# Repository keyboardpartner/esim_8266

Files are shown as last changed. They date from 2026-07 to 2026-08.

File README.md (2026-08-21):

# EPROM Simulator Uploader

### ESP8266 Project for PlatformIO with Arduino Framework

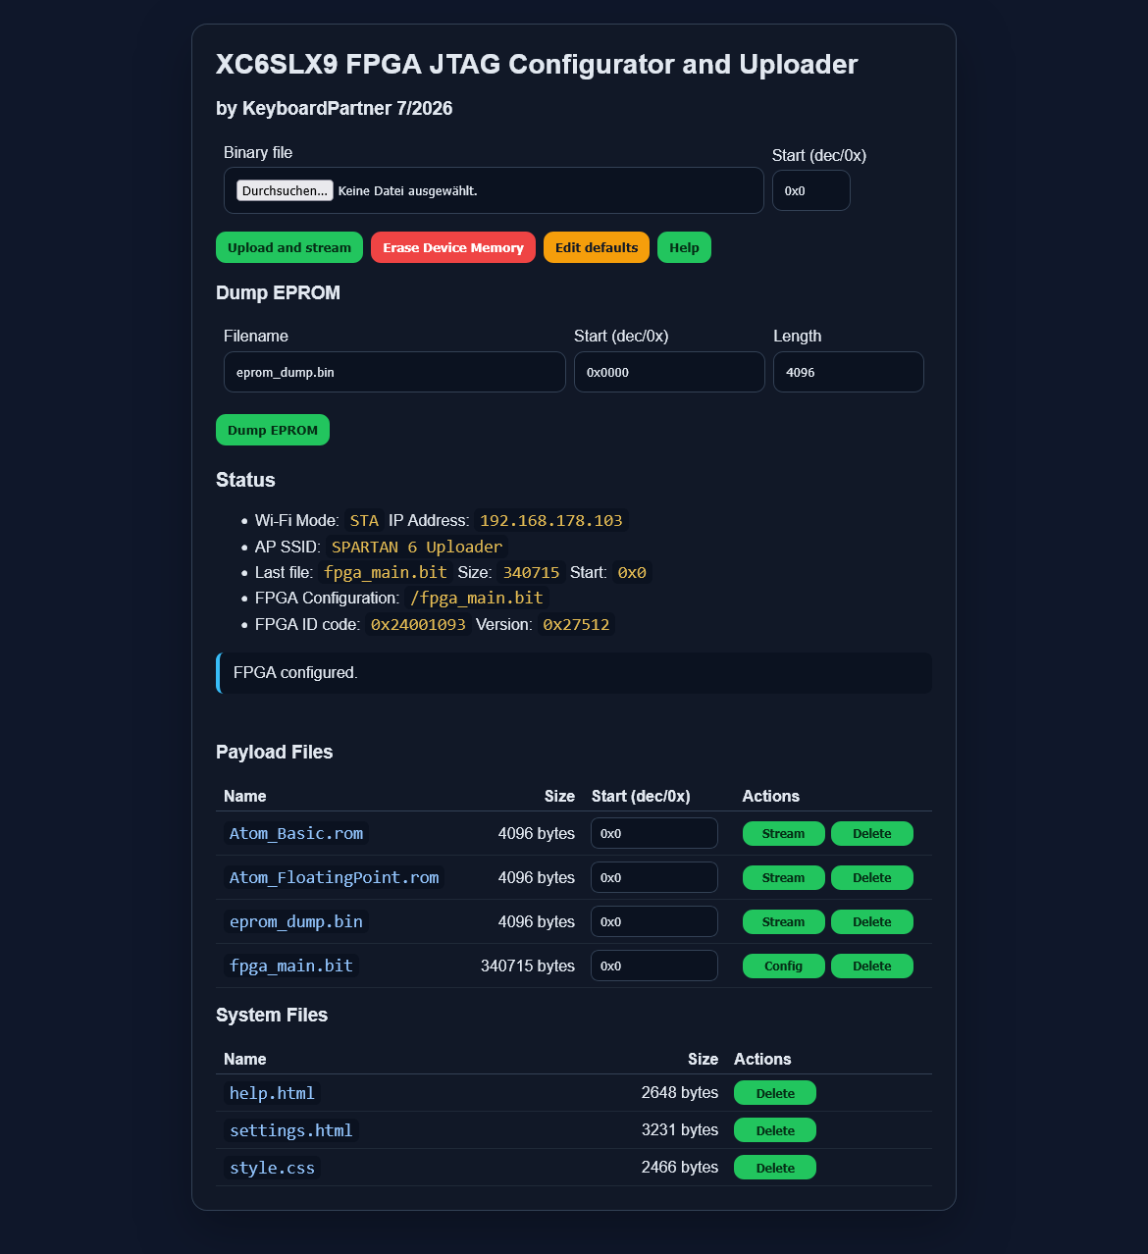
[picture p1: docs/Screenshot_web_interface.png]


For development of legacy computer systems and embedded controllers, an EPROM simulator is mandatory. Unfortunately, they are no longer popular and availability is sparse, while older models lack an appropriate interface. I made a few versions shown here. Set *#defines* in *main.cpp* accordingly.

The ESP8266 provides a nice web interface along with help page. For use without web interface, my [ESP8266 EPROM/SRAM Simulator Uploader](https://github.com/keyboardpartner/ESIM_Uploader) may be used to transfer files to the device.

### MOJO V3 FPGA Support

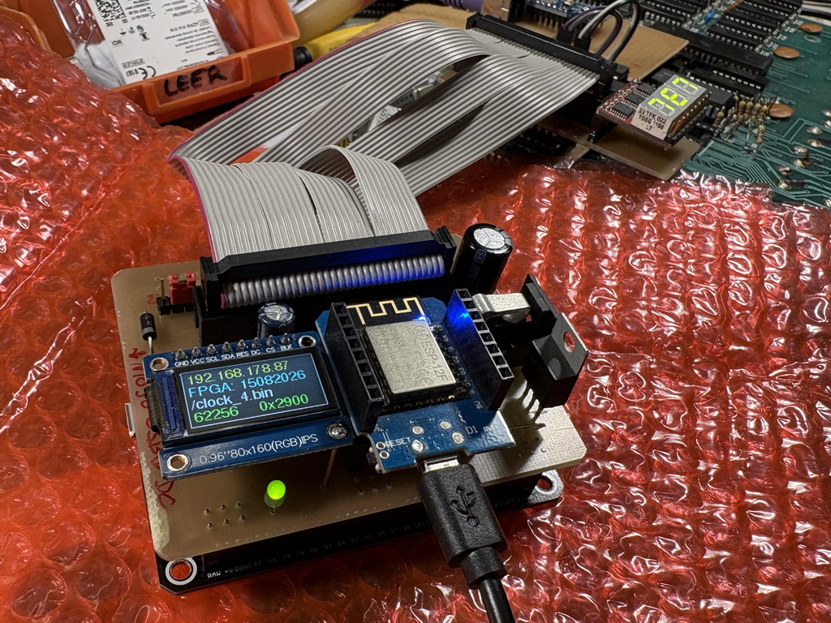
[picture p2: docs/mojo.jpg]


Using a MOJO V3 FPGA board as EPROM simulator allows for 64 KByte EPROMs and SRAMs, merely by using internal FPGA BRAMs. MOJO is a FPGA board from *embeddedmicro.com*, formerly advertized as "open source". Unfortunately, the manufacturer ceased operation, and documentation is sparse now. This is how not to do "open source"!

However, some cheap rip-offs are still available through Aliexpress. The original MOJO design is rather bad, using an AVR for (slowly!) uploading the configuration bitstream from an SPI flash via *Master SelectMAP* mode (instead of attaching the SPI flash direcly to FPGA; by blocking the FPGA, flashing would have been possible as well).

I once made a [MOJO BIT file Uploader for Windows](https://github.com/keyboardpartner/MOJO_uploader) that flashes the SPI memory, but here a different approach is used: I send the FPGA configuration through JTAG (pins available on MOJO SV1). So the FPGA configuration may be uploaded and selected by web interface on-the-fly. The AVR on MOJO board is blocked by permanent reset. My fast JTAG loader sends the 334 KByte bitstream file for FPGA XILINX XC6SLX9 from LittleFS in about 920 ms (instead of 3.4 seconds of known version from RSP, see below), which is even faster than the ill-fated MOJO approach.

For MOJO-like boards with Xilinx XC9SLX9 FPGA, ensure the correct bitstream (default "fpga_main.bit") is uploaded to file system. The bitstream is loaded into the FPGA during startup configuration via JTAG.

This version can be used as RAM emulator for 6264 or 62256 SRAMs, like the GODIL version. Note that MOJO **does not provide logic level translators**. I think a 220R resistor in series to each logic line will do, protecting inputs from host circuit's 5V levels. Tested with several old home computers; seems they all work with 3.3V logic levels.

The MOJO version supports the following devices: 2716, 2732, 2764, 27128, 27256 and 27512 EPROMs, 2532 EPROMs, 2332 and 2364 PROMs, 6116, 6264 and 62256 SRAMs, PicoBlaze 3 and 6 core ROMs. I also plan for a MOS 6502 emulation with monitor functions.

### 0.96" TFT Support

A 0.96" TFT (optional) displays status messages, IP number, FPGA image version, file used, device emulated and start address info for the MOJO version. The TFT will work on other versions (instead of DY1 display) too, but only the MOJO PCB provides installation.

### ESIM Support

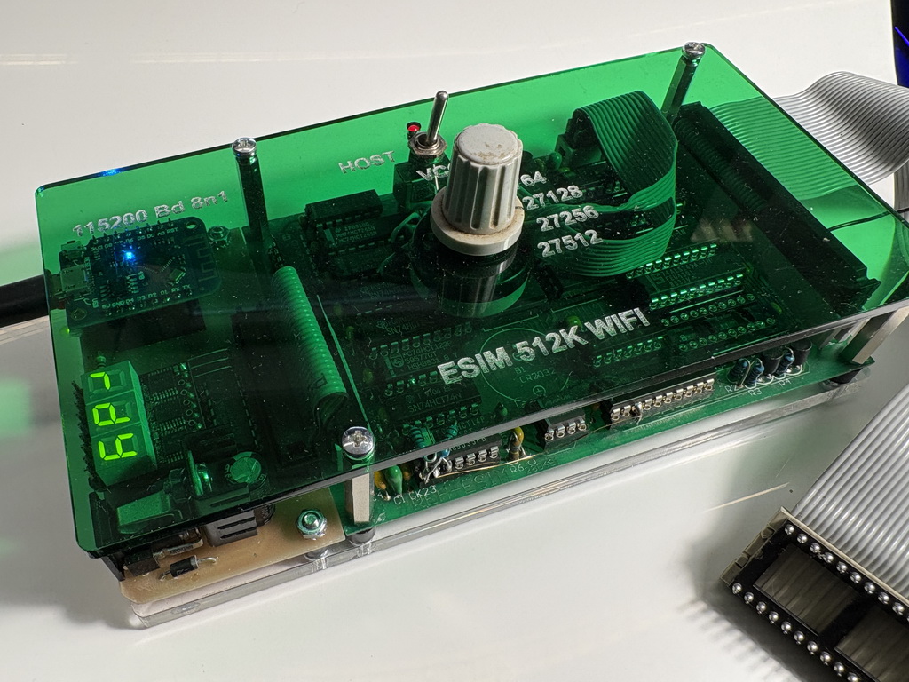
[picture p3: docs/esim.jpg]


ESP8266 used as an upload tool for old ESIM EPROM Simulator from c't magazine, issue 9/1991. Instead of obsolete Centronix port, outputs stream of data to 74HC595 shift register. Pulls /STROBE low on each byte sent. Supports 2764 up tp 27512 EPROMs. Unfortunately, ESIM does not support readback or setting a start address; uploads will always start at EPROM address 0x0000.

#### Pinout ESIM

Centronix Sub-D-25 for IBM PC, box pin header, 26 pins. Sub-D-25 pins in brackets

| PFS-26 Pin | Sub-D-25 Pin | Signal | PFS-26 Pin | Sub-D-25 Pin | Signal |
| --- | --- | --- | --- | --- | --- |
| 1  | (1)  | /STB | 2  | (14) | nc |
| 3  | (2)  | D0 | 4  | (15) | nc |
| 5  | (3)  | D1 | 6  | (16) | nc |
| 7  | (4)  | D2 | 8  | (17) | nc |
| 9  | (5)  | D3 | 10 | (18) | GND |
| 11 | (6)  | D4 | 12 | (19) | GND |
| 13 | (7)  | D5 | 14 | (20) | GND |
| 15 | (8)  | D6 | 16 | (21) | GND |
| 17 | (9)  | D7 | 18 | (22) | GND |
| 19 | (10) | nc (ACK) | 20 | (23) | GND |
| 21 | (11) | GND (BUSY) | 22 | (24) | GND |
| 23 | (12) | nc | 24 | (25) | GND |
| 25 | (13) | VCC-Host | 26 | (-)  | VCC-Host |

### CONITEC PEPS Support

New: now supports even older PEPS EPROM Simulator from c't 5/1985, page 85. This design uses a special serial transmission; due to the protocol's nature, the byte output routine uses slower bit-banging instead of SPI. EPROM size is limited to 27128 (16 KBytes). Find the old article in /docs folder.

### GODIL FPGA Support

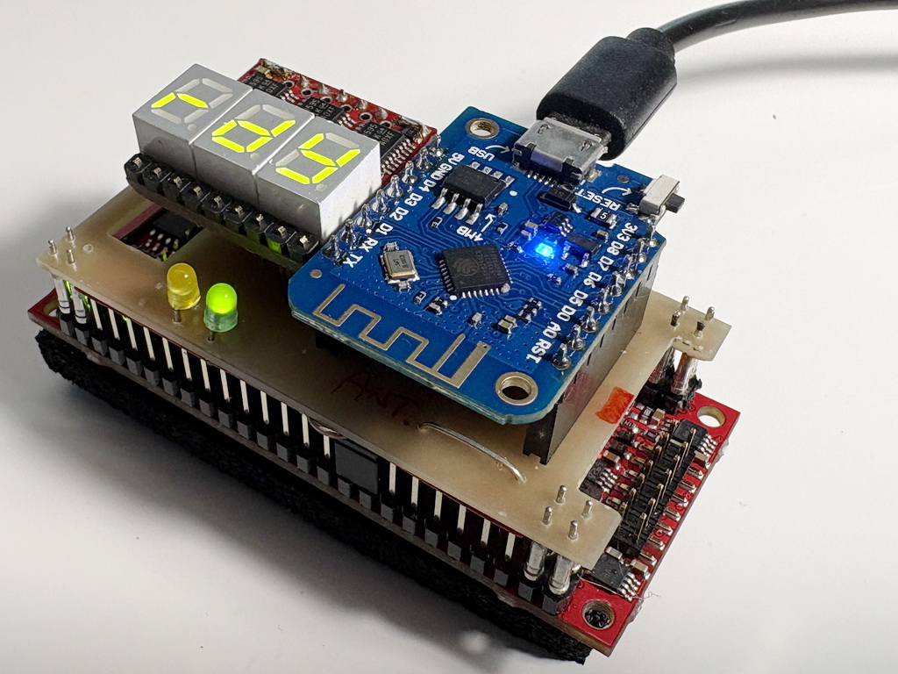
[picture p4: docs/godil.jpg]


Uses the now legendary GODIL 40 from [OHO electronic](https://www.oho-elektronik.de/). These are FPGA modules sold by [Trenz electronic](https://www.trenz-electronic.de/de) some time ago, but you may still find them on the web. Supports EPROMs up to 27256 (32 KByte) due to limitations of internal FPGA BRAMs. Needs some jumpers for Vcc on GODIL, as to switch between 24-pin and 28-pin EPROMs. GODIL has internal logic level translators, so it is compatible with 5V systems.

As well as the MOJO version, it can be used as RAM emulator for 6264 or 62256 SRAMs; in this case, you may read back the RAM contents from host system. Used it to recover old programs from my very first computer, an Acorn ATOM from 1981, using the rom_adapter_2 circuit. See /pcb folder. 

You need a JTAG adaptor to program GODIL's internal SPI flash. Prepare to do some VHDL coding, as this version does not provide features seen on the MOJO version.

### OHO DY1 Support

All modules support the OHO DY1 display, a 3-digit 7-segment LED module with SPI connection, handy for displaying short messages, IP numbers etc. You may omit the DY1 display and use serial monitoring instead (to get your IP number and to set password/SSID).

### PCBs

For each version, I designed a one-layer PCB optimized for milling. Can be handled by JCLPCB, though. There are also designs for ROM/RAM adaptors. See /pcb folder. 

PCB design done with EasyPC from NumberOne Systems.

Useful links:

[ESP8266 EPROM/SRAM Simulator Uploader](https://github.com/keyboardpartner/ESIM_Uploader) Windows CLI Upload tool, sends files to EPROM Simulator Uploader via COM port instead of web interface

[MOJO BIT file Uploader for Windows](https://github.com/keyboardpartner/MOJO_uploader) (not needed here, but anyway)

[MOJO v3 Bootloader and firmware](https://github.com/embmicro/mojo-bootloader/blob/master/Caterina.c)

[JTAG Player for ESP8266](https://github.com/rsp-esl/esp8266_jtag_fpga) (slow, as mentioned above)

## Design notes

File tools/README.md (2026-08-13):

# Tools for EPROM Simulator Uploader

### GODIL Tools



For programming the GODIL's internal SPI flash, you need a JTAG adaptor from Digilent like JTAG-SPI USB Full-Speed RevC or never. While the FPGA can be loaded with *Digilent Adept* app (volatile, good for development), you need the CLI-based Digilent *sfutil.exe* to permanently store the FPGA configuration in it's SPI flash. Provided here are two drag & drop capable batch files to read the flash mem's ID code and to program it via *sfutil.exe*.

Useful links:

[Digilent Adept Overview](https://digilent.com/shop/software/digilent-adept/)

[Digilent Adept Download](https://lp.digilent.com/complete-adept-utilities-download)

[Digilent SFUTIL SPI flash utility (Windows)](https://digilent.com/reference/software/serial-flash-utility/start)

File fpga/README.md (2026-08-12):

# EPROM Simulator Uploader - FPGA Sources

Copy contents to own Xilinx ISE FPGA project folder and open fpga_main.xise there. Add **one** UCF file (pin assignment) to your project (either GODIL or MOJO, not both). Also add memory IP core (*sram_32k.xco* for GODIL and *sram64k.xco* for MOJO) from *ipcore_dir* directory.

Data exchange happens through a 32-bit SPI register in FPGA. See *bram_wrapper.vhd* for SPI command set.

### Note to myself: Sources must be copied to this folder manually due to complexity of Xilinx ISE projects. Do not run ISE in this folder as it creates a mess.

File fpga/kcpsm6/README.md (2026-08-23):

# MOJO Picoblaze Demo

The XILINX Webpack ISE project *MojoFPGA_Picoblaze.xise* contains a Picoblaze CPU core which lets the onboard-LEDs blink, demonstrating the upload of Picoblaze Instruction ROM instead of using "hard-wired" BRAM contents defined in VHDL synthesis. 

After uploading the *mojo_pb_test.bit* configuration, stream the *picoblaze_test.dat* file to the Mojo FPGA using the Upload web page provided by the ESP8266.

For convenience, we provide a Drag&Drop batch file for [Ken Chapmman's 6-series picoblaze assembler](https://www.amd.com/en/products/adaptive-socs-and-fpgas/intellectual-property/picoblaze.html) for Windows PCs.

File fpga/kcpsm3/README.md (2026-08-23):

# MOJO Picoblaze Demo

The XILINX Webpack ISE project *MojoFPGA_Picoblaze.xise* contains a Picoblaze CPU core which lets the onboard-LEDs blink, demonstrating the upload of Picoblaze Instruction ROM instead of using a "hard-wired" BRAM contents defined in VHDL synthesis. This might be used for the GODIL as well (needs some project changes).

For convenience, we provide a compiled version of [Jan Viktorin's picoblaze assembler](https://github.com/jviki/kcpsm3) for Windows PCs and a Drag&Drop batch file. Note that Ken Chapman's original KCPSM3 no longer works on 64-Bit Windows.

After uploading the *mojo_pb_test.bit* configuration, stream the *picoblaze_test.dat* file to the Mojo FPGA using the Upload web page provided by the ESP8266.

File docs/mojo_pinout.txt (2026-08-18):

SV	SV Pin	FPGA UCF Pin	Function	ESP Pin
SV1	1		GND	
SV1	2		VCC 5V	
SV1	3		GND	
SV1	4		VCC 3V3	
SV1	5	P73	SUSPEND	
SV1	6	P71	DONE_2	
SV1	7	P58	IO_L14P_D11_2	
SV1	8	P57	IO_L14N_D12_2	
SV1	9	P67	IO_L2P_CMPCLK_2 	
SV1	10	P66	IO_L2N_CMPMOSI_2 	
SV1	11	P75	IO_L74P_AWAKE_1 	
SV1	12	P74	IO_L74N_DOUT_BUSY_1	
SV1	13	P79	IO_L47P_1 	
SV1	14	P78	IO_L47N_1 	
SV1	15	P81	IO_L46P_1 	
SV1	16	P80	IO_L46N_1 	
SV1	17	P83	IO_L45P_1 	
SV1	19	P85	IO_L43P_GCLK5_1 	
SV1	19	P82	IO_L45N_1 	
SV1	20	P84	IO_L43N_GCLK4_1 	
SV1	21	P88	IO_L42P_GCLK7_1 	
SV1	22	P87	IO_L42N_GCLK6_TRDY1_1 	GPIO 15 /SS
SV1	23	P93	IO_L41P_GCLK9_IRDY1_1 	GPIO 13 MOSI
SV1	24	P92	IO_L41N_GCLK8_1 	GPIO 12 MISO
SV1	25	P95	IO_L40P_GCLK11_1 	GPIO 14 SCLK
SV1	26	P94	IO_L40N_GCLK10_1 	GPIO 16 STRB
SV1	27	P98	IO_L34P_1 	
SV1	28	P97	IO_L34N_1 	
SV1	29	P100	IO_L33P_1 	
SV1	30	P99	IO_L33N_1 	
SV1	31	P102	IO_L32P_1 	
SV1	32	P101	IO_L32N_1 	
SV1	33	P105	IO_L1P_1 	
SV1	34	P104	IO_L1N_VREF_1 	
SV1	35	P112	IO_L66P_SCP1_0 	
SV1	36	P111	IO_L66N_SCP0_0 	
SV1	37	P115	IO_L65P_SCP3_0 	
SV1	38	P114	IO_L65N_SCP2_0 	
SV1	39	P117	IO_L64P_SCP5_0 	
SV1	40	P116	IO_L64N_SCP4_0 	
SV1	41	P119	IO_L63P_SCP7_0 	
SV1	42	P118	IO_L63N_SCP6_0 	
SV1	43	P121	IO_L62P_0 	
SV1	44	P120	IO_L62N_VREF_0 	
SV1	45	P107	TMS 	GPIO 2
SV1	46	P106	TDO 	GPIO 4
SV1	47	P110	TDI 	GPIO 0
SV1	48	P109	TCK 	GPIO 5
SV1	49	P38	IO_L65N_CSO_B_2	
SV1	50		GND	
SV	SV Pin	FPGA UCF Pin	Function	
SV2	1		GND	
SV2	2		VCC 5V	
SV2	3		GND	
SV2	4		VCC 3V3	
SV2	5	P31	IO_L31P_GCLK31_D14_2	
SV2	6	P50	IO_L31N_GCLK30_D15_2	
SV2	7	P41	IO_L64P_2	
SV2	8	P40	IO_L64N_2	
SV2	9	P35	IO_L1P_3 	
SV2	10	P34	IO_L1N_VREF_3 	
SV2	11	P33	IO_L2P_3 	
SV2	12	P32	IO_L2N_3 	
SV2	13	P30	IO_L36P_3 	
SV2	14	P29	IO_L36N_3 	
SV2	15	P27	IO_L37P_3 	
SV2	16	P26	IO_L37N_3 	
SV2	17	P24	IO_L41P_GCLK27_3 	
SV2	18	P23	IO_L41N_GCLK26_3 	
SV2	19	P22	IO_L42P_GCLK25_TRDY2_3 	
SV2	20	P21	IO_L42N_GCLK24_3 	
SV2	21	P17	IO_L43P_GCLK23_3 	
SV2	22	P16	IO_L43N_GCLK22_IRDY2_3 	
SV2	23	P15	IO_L44P_GCLK21_3 	
SV2	24	P14	IO_L44N_GCLK20_3 	
SV2	25	P12	IO_L49P_3 	
SV2	26	P11	IO_L49N_3 	
SV2	27	P10	IO_L50P_3 	
SV2	28	P9	IO_L50N_3 	
SV2	29	P8	IO_L51P_3 	
SV2	30	P7	IO_L51N_3 	
SV2	31	P6	IO_L52P_3 	
SV2	32	P5	IO_L52N_3 	
SV2	33	P2	IO_L83P_3 	
SV2	34	P1	IO_L83N_VREF_3 	
SV2	35	P144	IO_L1P_HSWAPEN_0 	
SV2	36	P143	IO_L1N_VREF_0 	
SV2	37	P142	IO_L2P_0 	
SV2	38	P141	IO_L2N_0 	
SV2	39	P140	IO_L3P_0 	
SV2	40	P139	IO_L3N_0 	
SV2	41	P138	IO_L4P_0 	
SV2	42	P137	IO_L4N_0 	
SV2	43	P134	IO_L34P_GCLK19_0 	
SV2	44	P133	IO_L34N_GCLK18_0 	
SV2	45	P132	IO_L35P_GCLK17_0 	
SV2	46	P131	IO_L35N_GCLK16_0 	
SV2	47	P127	IO_L36P_GCLK15_0 	
SV2	48	P126	IO_L36N_GCLK14_0 	
SV2	49	P124	IO_L37P_GCLK13_0 	
SV2	50	P123	IO_L37N_GCLK12_0

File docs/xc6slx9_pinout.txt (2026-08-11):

Device/Package 6slx9tqg144 Wed Mar 31 17:26:10 2010 

Pin	Bank	BUFIO2	Pin Description 

P144	0	TL	IO_L1P_HSWAPEN_0 
P143	0	TL	IO_L1N_VREF_0 
P142	0	TL	IO_L2P_0 
P141	0	TL	IO_L2N_0 
P140	0	TL	IO_L3P_0 
P139	0	TL	IO_L3N_0 
P138	0	TL	IO_L4P_0 
P137	0	TL	IO_L4N_0 
P134	0	TL	IO_L34P_GCLK19_0 
P133	0	TL	IO_L34N_GCLK18_0 
P132	0	TL	IO_L35P_GCLK17_0 
P131	0	TL	IO_L35N_GCLK16_0 
P127	0	TR	IO_L36P_GCLK15_0 
P126	0	TR	IO_L36N_GCLK14_0 
P124	0	TR	IO_L37P_GCLK13_0 
P123	0	TR	IO_L37N_GCLK12_0 
P121	0	TR	IO_L62P_0 
P120	0	TR	IO_L62N_VREF_0 
P119	0	TR	IO_L63P_SCP7_0 
P118	0	TR	IO_L63N_SCP6_0 
P117	0	TR	IO_L64P_SCP5_0 
P116	0	TR	IO_L64N_SCP4_0 
P115	0	TR	IO_L65P_SCP3_0 
P114	0	TR	IO_L65N_SCP2_0 
P112	0	TR	IO_L66P_SCP1_0 
P111	0	TR	IO_L66N_SCP0_0 
P109	NA	NA	TCK 
P110	NA	NA	TDI 
P107	NA	NA	TMS 
P106	NA	NA	TDO 
P105	1	RT	IO_L1P_1 
P104	1	RT	IO_L1N_VREF_1 
P102	1	RT	IO_L32P_1 
P101	1	RT	IO_L32N_1 
P100	1	RT	IO_L33P_1 
P99	1	RT	IO_L33N_1 
P98	1	RT	IO_L34P_1 
P97	1	RT	IO_L34N_1 
P95	1	RT	IO_L40P_GCLK11_1 
P94	1	RT	IO_L40N_GCLK10_1 
P93	1	RT	IO_L41P_GCLK9_IRDY1_1 
P92	1	RT	IO_L41N_GCLK8_1 
P88	1	RB	IO_L42P_GCLK7_1 
P87	1	RB	IO_L42N_GCLK6_TRDY1_1 
P85	1	RB	IO_L43P_GCLK5_1 
P84	1	RB	IO_L43N_GCLK4_1 
P83	1	RB	IO_L45P_1 
P82	1	RB	IO_L45N_1 
P81	1	RB	IO_L46P_1 
P80	1	RB	IO_L46N_1 
P79	1	RB	IO_L47P_1 
P78	1	RB	IO_L47N_1 
P75	1	RB	IO_L74P_AWAKE_1 
P74	1	RB	IO_L74N_DOUT_BUSY_1           ############  DOUT This output pin is used during readback. 
P73	NA	NA	SUSPEND  
P72	2	NA	CMPCS_B_2 
P71	2	NA	DONE_2                        ############  DONE1 = FPGA configured,  Mojo: AVR PC6
P70	2	BR	IO_L1P_CCLK_2                 ############  CCLK Configuration clock, Mojo: AVR PD0
P69	2	BR	IO_L1N_M0_CMPMISO_2           #### M0 ####  M0  LOW-Pegel = SelectMAP
P67	2	BR	IO_L2P_CMPCLK_2 
P66	2	BR	IO_L2N_CMPMOSI_2 
P65	2	BR	IO_L3P_D0_DIN_MISO_MISO1_2    ############  DIN + SelectMAP D0, Mojo: AVR PB7 (!)
P64	2	BR	IO_L3N_MOSI_CSI_B_MISO0_2     ############  Active-Low chip select to enable the SelectMAP data bus 
P62	2	BR	IO_L12P_D1_MISO2_2            ############  SelectMAP D1, Mojo: AVR PB6 (!)
P61	2	BR	IO_L12N_D2_MISO3_2            ############  SelectMAP D2, Mojo: AVR PB5 (!)
P60	2	BR	IO_L13P_M1_2                  #### M1 ####  M1  HI-Pegel = SelectMAP
P59	2	BR	IO_L13N_D10_2 
P58	2	BR	IO_L14P_D11_2 
P57	2	BR	IO_L14N_D12_2 
P56	2	BR	IO_L30P_GCLK1_D13_2 
P55	2	BR	IO_L30N_GCLK0_USERCCLK_2 
P51	2	BL	IO_L31P_GCLK31_D14_2 
P50	2	BL	IO_L31N_GCLK30_D15_2 
P48	2	BL	IO_L48P_D7_2                  ############  SelectMAP D7, Mojo: AVR SS   PB0 (!)
P47	2	BL	IO_L48N_RDWR_B_VREF_2         ############  Determines the direction of the D[x:0] data bus, 0 = inputs, 1 = outputs
P46	2	BL	IO_L49P_D3_2                  ############  SelectMAP D3, Mojo: AVR PB4 (!)
P45	2	BL	IO_L49N_D4_2                  ############  SelectMAP D4, Mojo: AVR MISO PB3 (!)
P44	2	BL	IO_L62P_D5_2                  ############  SelectMAP D5, Mojo: AVR MOSI PB2 (!)
P43	2	BL	IO_L62N_D6_2                  ############  SelectMAP D6, Mojo: AVR SCK  PB1 (!)
P41	2	BL	IO_L64P_D8_2 
P40	2	BL	IO_L64N_D9_2 
P39	2	BL	IO_L65P_INIT_B_2              ############  Mojo: AVR PD5
P38	2	BL	IO_L65N_CSO_B_2               ############  Not used in single FPGA applications
P37	2	NA	PROGRAM_B_2                   ############  PROGRAM_B Active-Low asynchronous full-chip reset, Mojo: AVR PC7
P35	3	LB	IO_L1P_3 
P34	3	LB	IO_L1N_VREF_3 
P33	3	LB	IO_L2P_3 
P32	3	LB	IO_L2N_3 
P30	3	LB	IO_L36P_3 
P29	3	LB	IO_L36N_3 
P27	3	LB	IO_L37P_3 
P26	3	LB	IO_L37N_3 
P24	3	LB	IO_L41P_GCLK27_3 
P23	3	LB	IO_L41N_GCLK26_3 
P22	3	LB	IO_L42P_GCLK25_TRDY2_3 
P21	3	LB	IO_L42N_GCLK24_3 
P17	3	LT	IO_L43P_GCLK23_3 
P16	3	LT	IO_L43N_GCLK22_IRDY2_3 
P15	3	LT	IO_L44P_GCLK21_3 
P14	3	LT	IO_L44N_GCLK20_3 
P12	3	LT	IO_L49P_3 
P11	3	LT	IO_L49N_3 
P10	3	LT	IO_L50P_3 
P9	3	LT	IO_L50N_3 
P8	3	LT	IO_L51P_3 
P7	3	LT	IO_L51N_3 
P6	3	LT	IO_L52P_3 
P5	3	LT	IO_L52N_3 
P2	3	LT	IO_L83P_3 
P1	3	LT	IO_L83N_VREF_3 
P108	NA	NA	GND 
P113	NA	NA	GND 
P13	NA	NA	GND 
P130	NA	NA	GND 
P136	NA	NA	GND 
P25	NA	NA	GND 
P3	NA	NA	GND 
P49	NA	NA	GND 
P54	NA	NA	GND 
P68	NA	NA	GND 
P77	NA	NA	GND 
P91	NA	NA	GND 
P96	NA	NA	GND 
P129	NA	NA	VCCAUX 
P20	NA	NA	VCCAUX 
P36	NA	NA	VCCAUX 
P53	NA	NA	VCCAUX 
P90	NA	NA	VCCAUX 
P128	NA	NA	VCCINT 
P19	NA	NA	VCCINT 
P28	NA	NA	VCCINT 
P52	NA	NA	VCCINT 
P89	NA	NA	VCCINT 
P122	0	NA	VCCO_0 
P125	0	NA	VCCO_0 
P135	0	NA	VCCO_0 
P103	1	NA	VCCO_1 
P76	1	NA	VCCO_1 
P86	1	NA	VCCO_1 
P42	2	NA	VCCO_2 
P63	2	NA	VCCO_2 
P18	3	NA	VCCO_3 
P31	3	NA	VCCO_3 
P4	3	NA	VCCO_3 

Total Number of Pins generated, 144

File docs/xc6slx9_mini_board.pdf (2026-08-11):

Xilinx Spartan 6 FPGA | XC6SLX9 Mini Board

# Xilinx XC6SLX9 Mini Board

## User's Guide

# 1. Introduction

XC6SLX9 Mini Board is an easy-to-use FPGA platform based on Xilinx Spartan 6 series FPGA. It was initially designed for low cost with a everyone affordable price. Up to 72 I/O breakout makes it suitable in high pin count applications. You can connect the I/Os to your peripheral modules with several flying wires to quickly build a prototype project. Also, one USB to UART bridge is integrated on board, only a USB cable is needed for power supply and data communication. Because of its compact size and abundant IOs, it can be easily embedded in your design as a core. This guide describes how to use Xilinx tools and XC6SLX9 Mini Board to learn FPGA as a beginner. If you are familiar with Xilinx design tools and the process of FPGA design, some sections could be ignored.

The XC6SLX9 Mini Board includes:
– Xilinx Spartan 6 FPGA － XC6SLX9-2TQG144C( Spartan-6 FPGA Family Overview (http://www.xilinx.com/support/documentation/data_sheets/ds160.pdf) ) – 64-Mbit SPI Flash memory ( W25Q64BV )
– USB to UART ( FT232RL (http://www.ftdichip.com/Products/ICs/FT232R.htm) ) with TXD, RXD activity LED Indicator
– Two groups of 2x20 expansion header ( 72 I/Os, +3.3V, +5V, GND )
– JTAG programming header, directly connected to Xilinx Platform Cable USB (http://www.xilinx.com/products/boards-and-kits/hw-usb-g.html)
– Two pushbuttons
– One reset pushbutton for reloading configuration file from external flash into FPGA – Eight LEDs for I/O status indication
– 50 MHz clock oscillator
– USB or external power supply ( can be powered with a 9V battery )

Board Size: 75(mm) x 49(mm)

| XC6SLX9 Mini Board Layout ( Top Side )

# 2. Get the tools ready

First, we must get the necessary software and hardware tools ready before starting a FPGA project. Three tools must be prepared:
1) ISE WebPACK Design Software — We use HDL( Hardware Description Language ) code like Verilog or VHDL to describe a digital circuit, code must be compiled and ultimately implemented into a circuit layout that can be programmed to FPGA device. ISE WebPACK Design Software is an fully integrated tool for this purpose provided by Xilinx.
2) XC6SLX9 Mini Board and one mini USB cable — This board includes a target FPGA device and some other necessary circuitry and peripherals to support the running of the device.
3) Xilinx Platform Cable USB or a parallel download cable — This is a programming tool to download an configuration file generated by ISE WebPACK to the internal SRAM of the target FPGA device or an external non-volatile memory.

## 2.1 Download and Install ISE WebPACK Design Software

Xilinx provides a free IDE software named ISE WebPACK for beginners. Although it has limited functions compare to other charged editions, but that's enough for most beginners. It's a complete solution for FPGA design offering HDL synthesis and simulation, implementation, device fitting, and JTAG programming. Please visit ISE WebPACK Design Software (http://www.xilinx.com/products/design-tools/ise-design-suite/ise-webpack.html) webpage for details and download (http://www.xilinx.com/support/download/index.html/content/xilinx/en/downloadNav/design-tools.html) it to you PC. Different versions are provided, but they have similar UI and basic functions. Of course the latest version will occupy more hardware disk space. So which version you choose depends on your PC. We use ISE WebPACK 14.1 for demonstration in this guide.

Note: If you have installed ISE WebPACK Software on your PC, you can ignore this section.
All the operations in the following sections are done on Windows 8.1 x64 operating system.

## 2.2 Install the ISE WebPACK Design Software

1) Unzip the download file and go to the setup directory, double-click xsetup.exe to start the installation process.

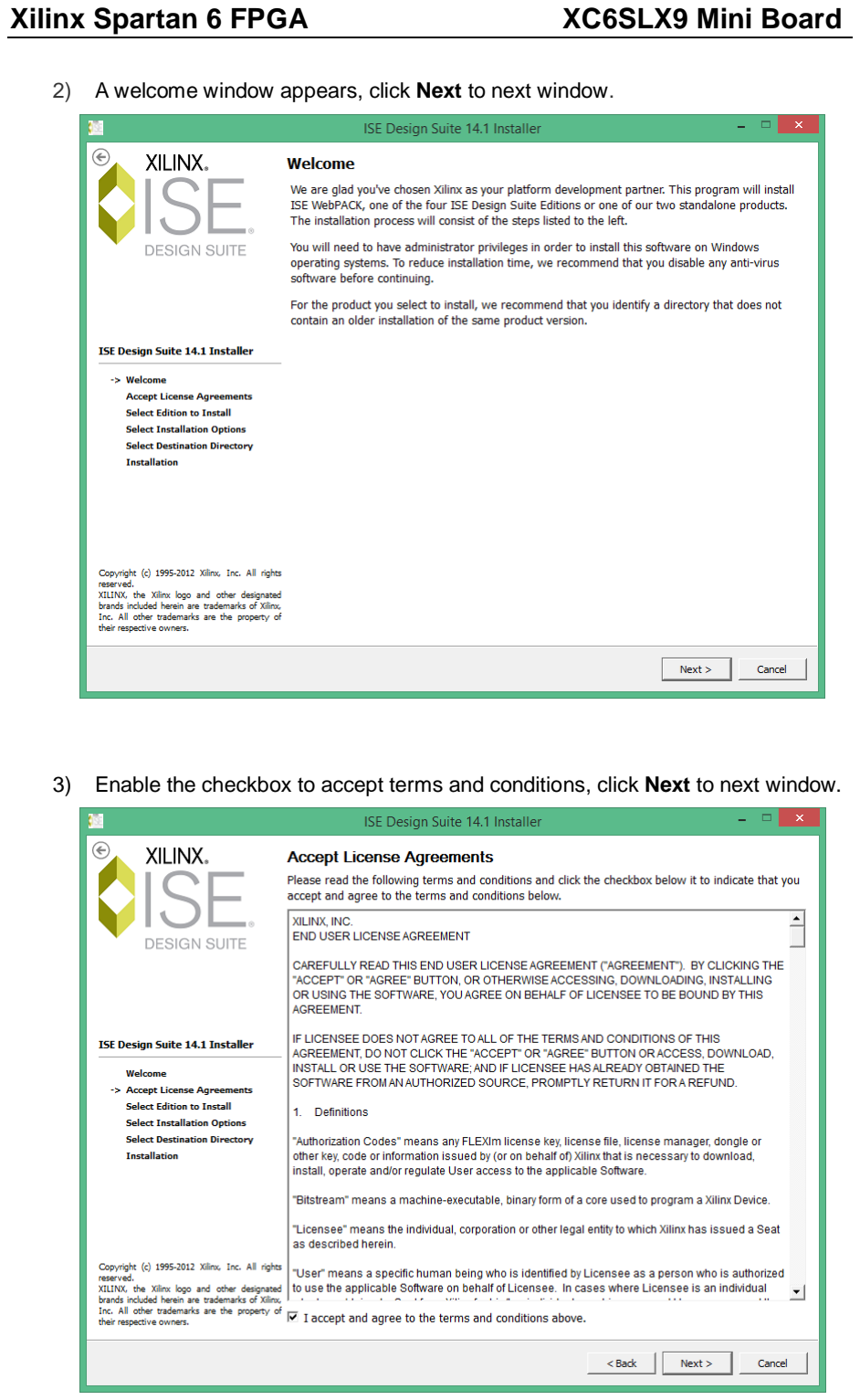
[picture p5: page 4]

2) A welcome window appears, click Next to next window.
3) Enable the checkbox to accept terms and conditions, click Next to next window.

4) Another license agreement window appears, enable the check box, and click Next to next window.
5) Differnent editions are contained in this ISE Design Suite. We select ISE WebPACK. Click Next to next window.

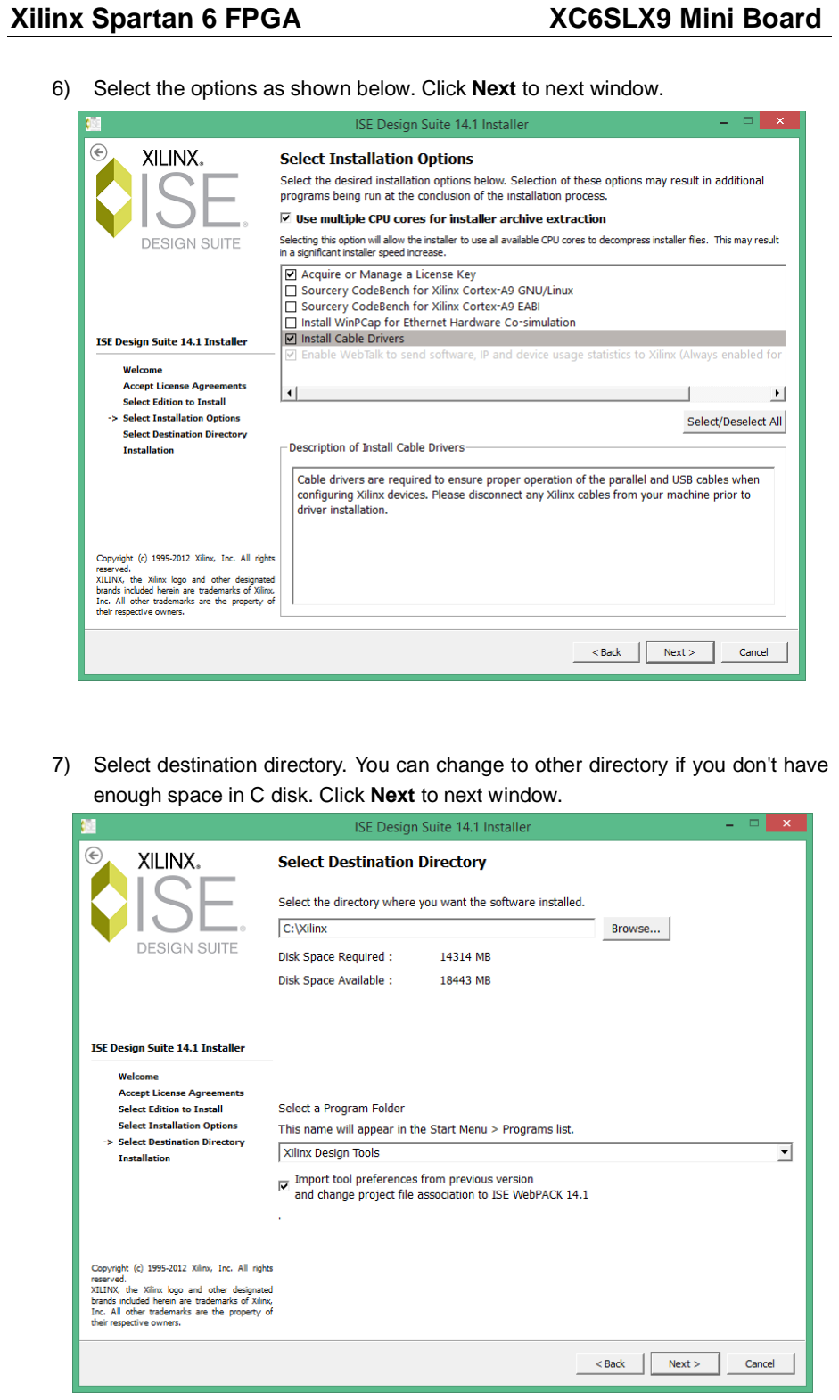
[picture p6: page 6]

6) Select the options as shown below. Click Next to next window.
7) Select destination directory. You can change to other directory if you don't have enough space in C disk. Click Next to next window.

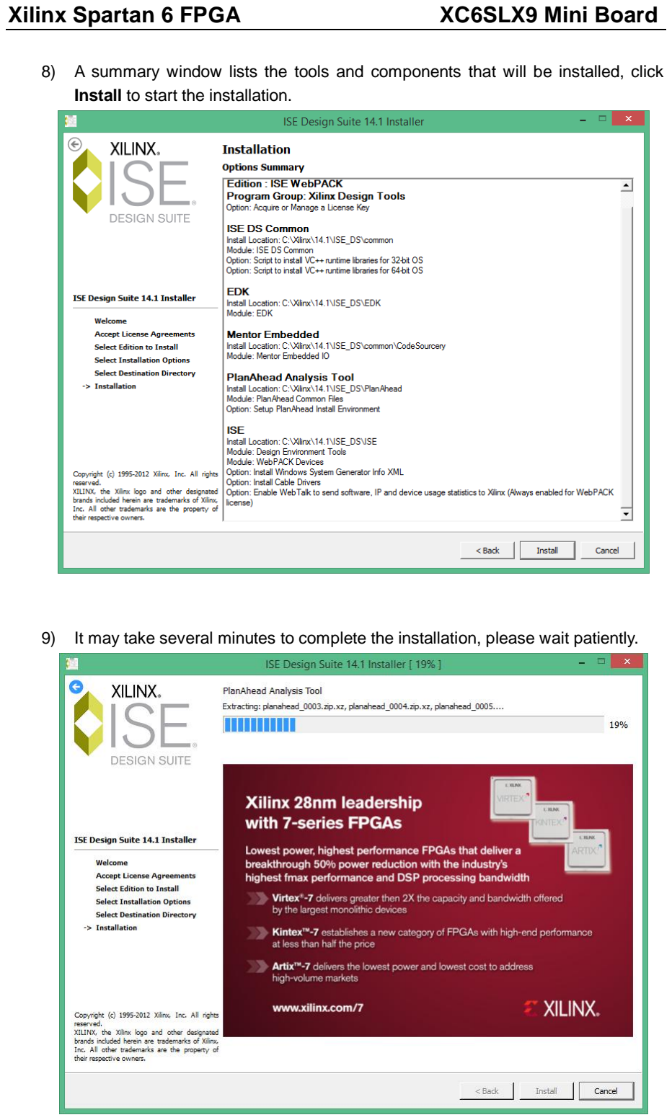
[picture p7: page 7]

8) A summary window lists the tools and components that will be installed, click Install to start the installation.
9) It may take several minutes to complete the installation, please wait patiently.

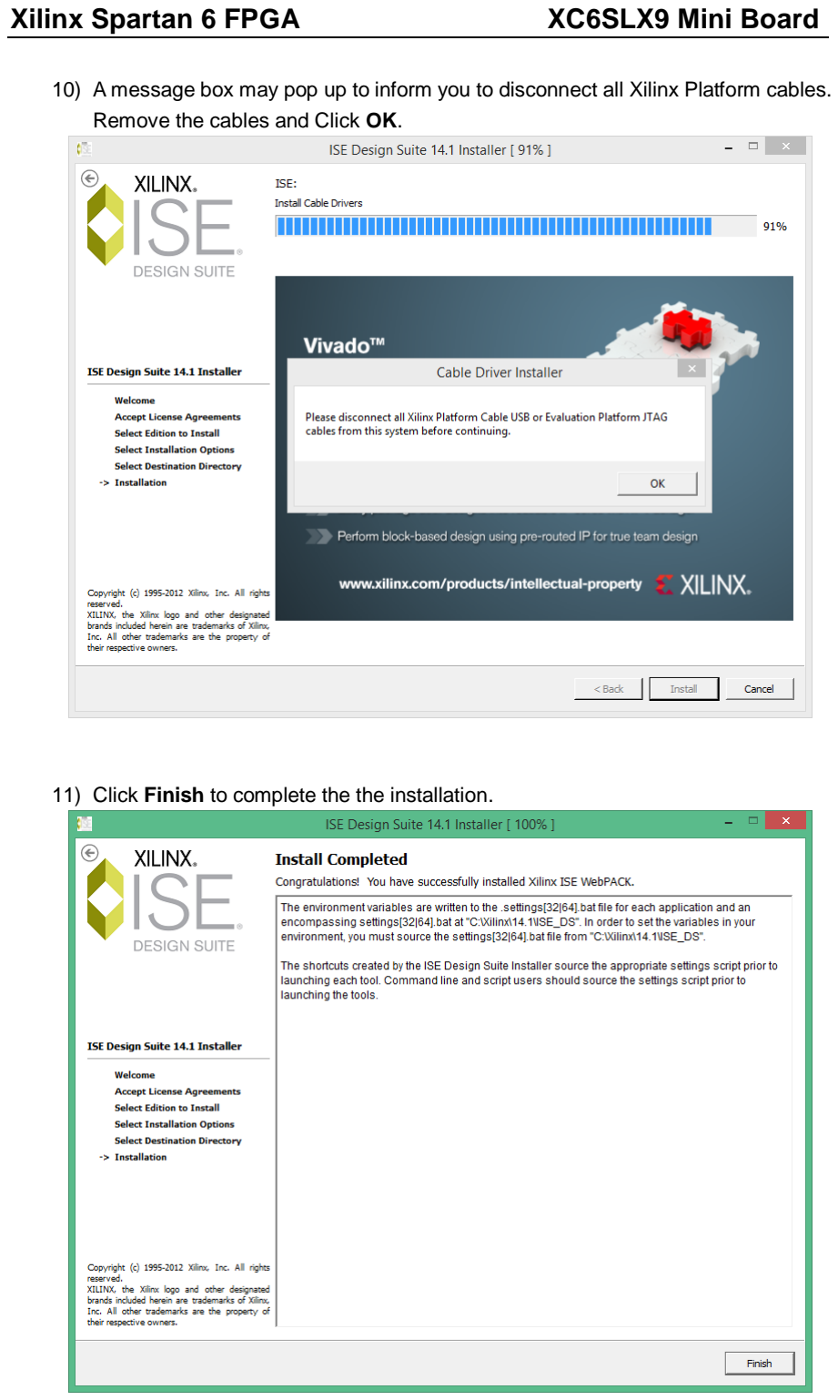
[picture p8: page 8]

10) A message box may pop up to inform you to disconnect all Xilinx Platform cables. Remove the cables and Click OK.
11) Click Finish to complete the the installation.

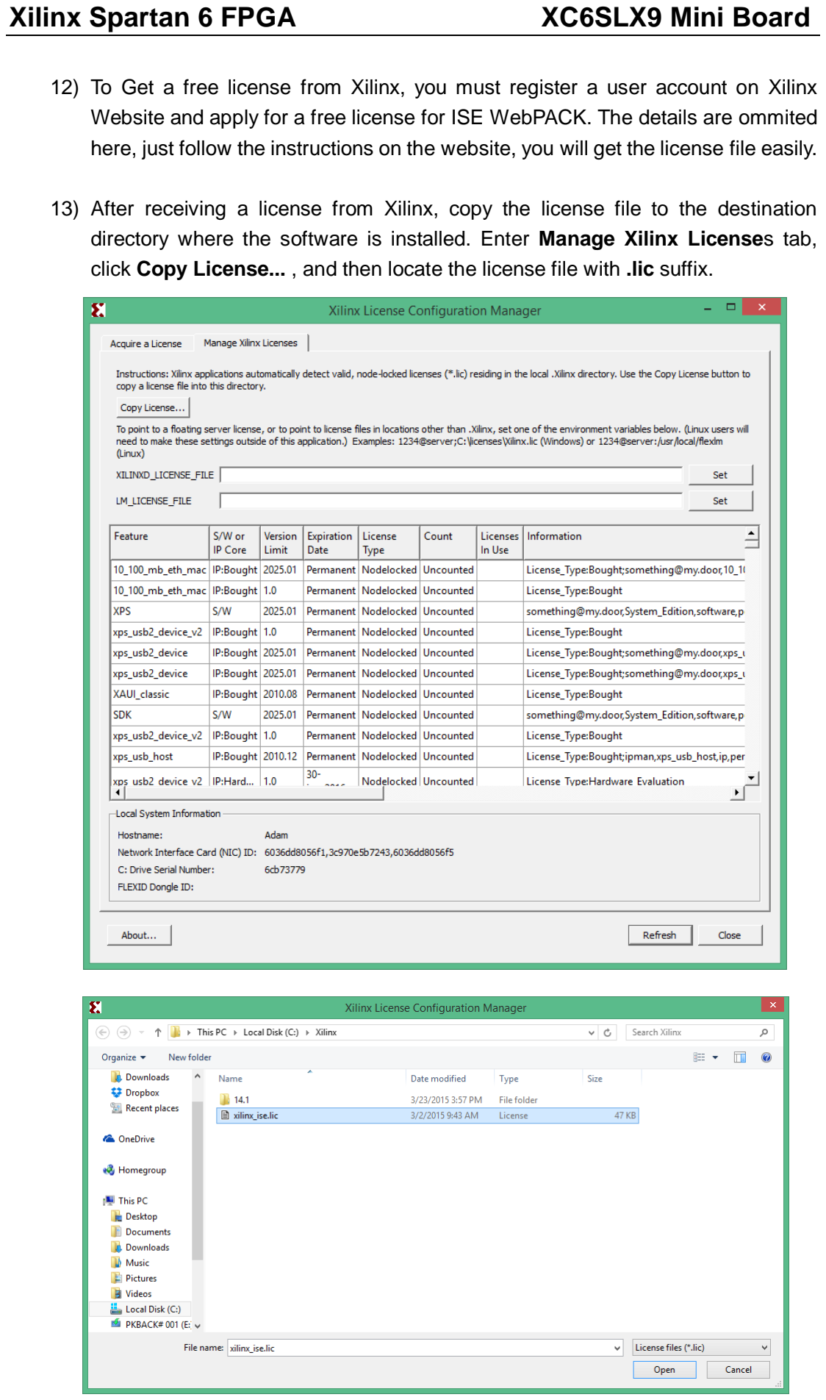
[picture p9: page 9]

12) To Get a free license from Xilinx, you must register a user account on Xilinx Website and apply for a free license for ISE WebPACK. The details are ommited here, just follow the instructions on the website, you will get the license file easily.
13) After receiving a license from Xilinx, copy the license file to the destination directory where the software is installed. Enter Manage Xilinx Licenses tab, click Copy License... , and then locate the license file with .lic suffix.

14) Congratulations! You have successfully installed and activated the software.

## 2.3 Setup the XC6SLX9 Mini Board

A USB connection is provided on XC6SLX9 Mini Board. It is intended for data communication and powering the board. FT232R is used as a USB to UART bridge. It is a very popular IC widely used in various USB converter cables. As usual, a device driver software must be installed before the operating system could successfully recognize and operate the device.

Note:
1) If your PC has the driver software installed before, the on-board FT232R will be enumerated as a common serial port when you connect the board to PC.
2) For the latest operating system like Windows 8, when a USB device detected, it will automatically find and install the driver for the device if windows update is enabled and internet connection is available.

The following instructions describe how to install the driver software for FT232R:

1) Power the board
Plug the XC6SLX9 mini board to your PC via a USB mini cable. When powered, the windows system will detect the insertion of a USB device and try to load a driver for this device. If windows fail to find the driver, it will list the device in the Device manager with a yellow exclamation mark, indicating the driver for this device is not found.

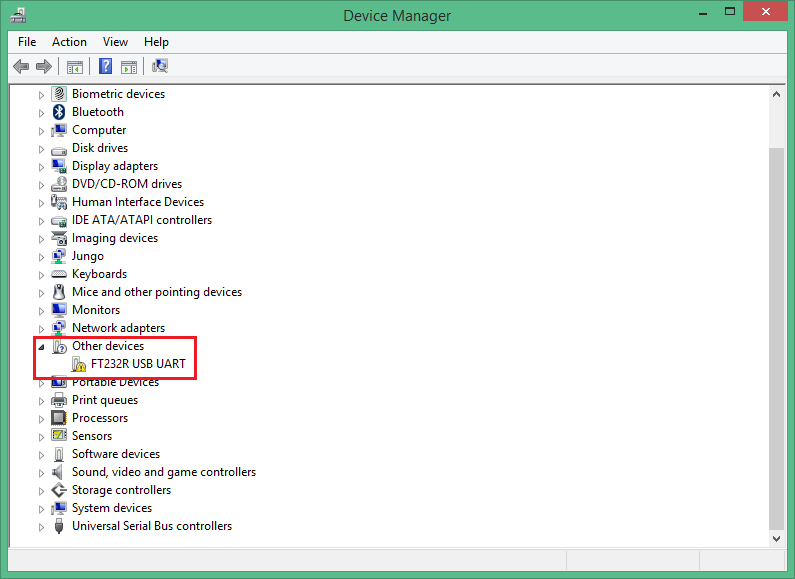
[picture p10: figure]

2) Install driver software automatically( Internet connection must be available )
- Right click on the FT232R USB UART, and select Update Driver Software...
- Select Search automatically for updated driver software
- Windows will automatically find and install the driver software, this will take a few seconds.
3) Install driver software manually
- Download (http://www.ftdichip.com/Drivers/VCP.htm) the driver software from FTDI website according to the edition of your operating system.
- Now, for Windows system, an executable version of this driver is available, unzip and run the executable file, driver will be installed automatically.
4) Verify the result
If the driver software is properly installed, the FT232R will function as a virtual serial port. And it will appear in the Device Manager list.

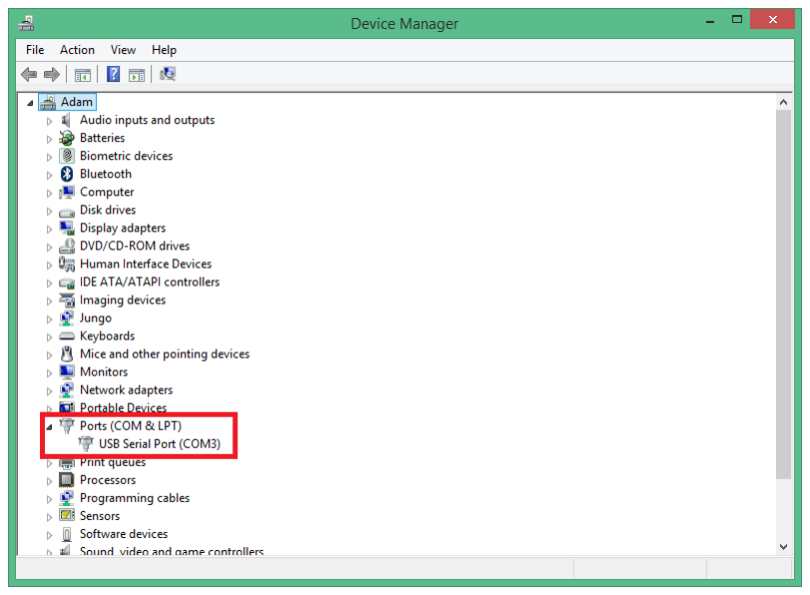
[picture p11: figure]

Note: You must get a serial port monitor software like PuTTY to hunt the serial port activities.

## 2.4 Setup Xilinx Platform Cable

A download cable is needed to program the configuration file to the target FPGA device. Xilinx provides USB download cable and parallel download cable, but USB cable is more popular because parallel port is eliminated in most new generation desktop or laptop PCs. We use Xilinx Platform Cable USB (http://www.xilinx.com/products/boards-and-kits/hw-usb-g.html) in all the demos and examples. A USB driver software is needed for this cable. It's integrated in the ISE WebPACK Design Software and has been installed in previous installation process. If the driver doesn't work or crashed, please read the application guide USB Cable Installation Guide, (http://www.xilinx.com/support/documentation/user_guides/ug344.pdf) and reinstall it. If driver software is properly installed, the cable named Xilinx USB Cable will appear in the Device Manager list.

# 3.Create your first FPGA Project

This section will guide you through the process of creating a simple FPGA project using Verilog HDL. We build an 8-bit barrel shifter that rotates one bit to the right in the interval of 1/4 second. The state of the shifter will be displayed on the eight LEDs. And finally, the object file will be downloaded to the target device on XC6SLX9 Mini Board and got verified.

Note: Some procedures like simulation, timing analysis, and creating constraints in FPGA design are omitted in this section.

1) Double-click ISE Project Navigator icon to start the IDE.
2) Select File -> New Project... The New Project Wizard appears.
3) Type Barrel_Shifter in the Project Name field. Browse to a location (directory path) for the new project. A Barrel_Shifter subdirectory will be created automatically. Select HDL in the Top-Level Source Type list. Click Next to move to the device property window.

4) Select a value for Device, Package, Speed and other properties as shown below.
5) A summary window appers.Click finish to comlete the project wizard.

6) Click Project -> New Sources... to create an HDL source.
7) Select Verilog Module, enter the file name Barrel_Shifter. Leave the file location to the default. Verify that the Add to project checkbox is selected. Click Next to next window.

8) Declare the input and output ports for the module as shown below,and then click Next to next window.

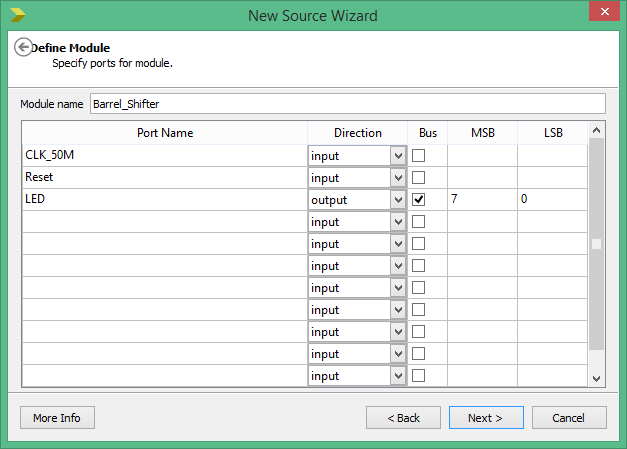
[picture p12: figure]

9) A summary window displays the information you entered in previous steps. Click Finish to complete the wizard if no errors found.

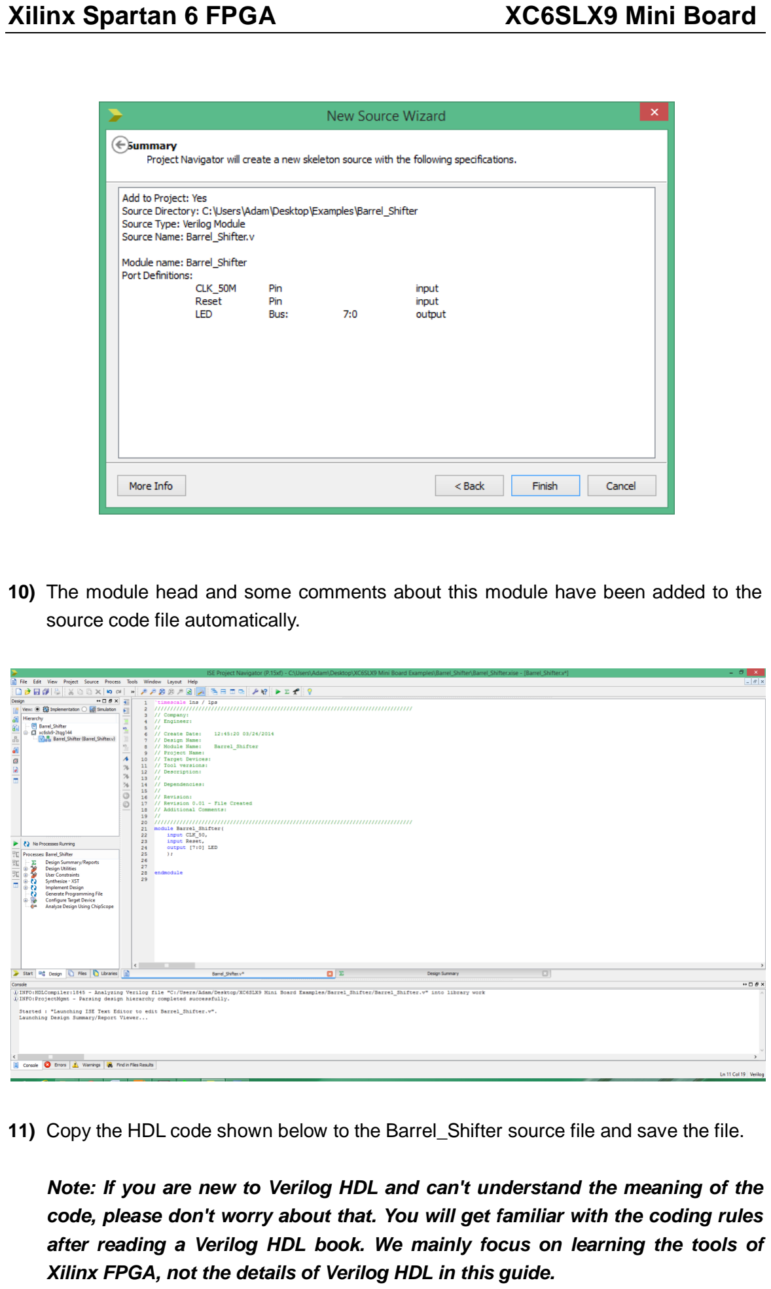
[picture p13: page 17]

10) The module head and some comments about this module have been added to the source code file automatically.
11) Copy the HDL code shown below to the Barrel_Shifter source file and save the file.

Note: If you are new to Verilog HDL and can't understand the meaning of the code, please don't worry about that. You will get familiar with the coding rules after reading a Verilog HDL book. We mainly focus on learning the tools of Xilinx FPGA, not the details of Verilog HDL in this guide.

module Barrel_Shifter( input CLK_50M, input Reset, output [7:0] LED ); reg [23:0] counter;
reg [7:0] shift_reg = 8'b0000_0001;
always@( posedge CLK_50M )
begin
if( Reset )
begin
counter <= 0;
end
else
counter <= counter + 1'b1; end
always @( posedge CLK_50M ) begin
if( Reset )
shift_reg <= 8'b0000_0001;
else
begin
if( counter == 24'b1011_1110_1011_1100_0010_0000 ) shift_reg <= { shift_reg[6:0],shift_reg[7] };
end
end
assign LED[7:0] = shift_reg[7:0];
endmodule
12) Double-click Implement Design in the process window. The project will be parsed and synthesized successfully.

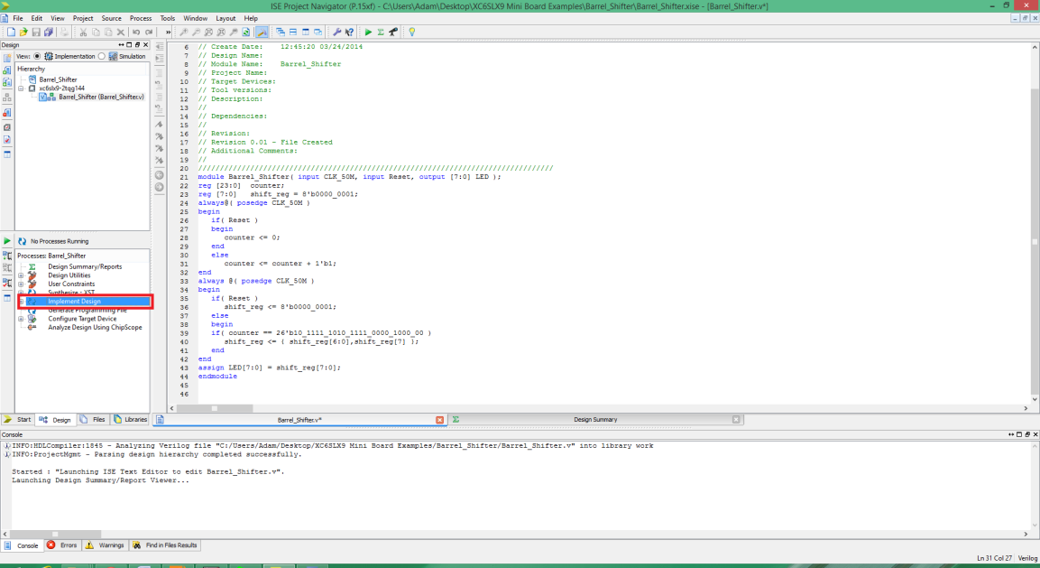
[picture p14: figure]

Note: Since the source code is verified, you don't need to correct any syntax errors or typos. In most cases, error is unavoidable for beginners, you should learn to analyze the error or warning tips printed in the Errors and Warnings window.

13) Click Tools -> PlanAhead -> I/O Pin Planning(PlanAhead)-Post-Synthesis... to assign pin locations. Then click Yes to automatically create a new constraint file add it to project.
14) Assign pin locations as shown below and then save the constraint.

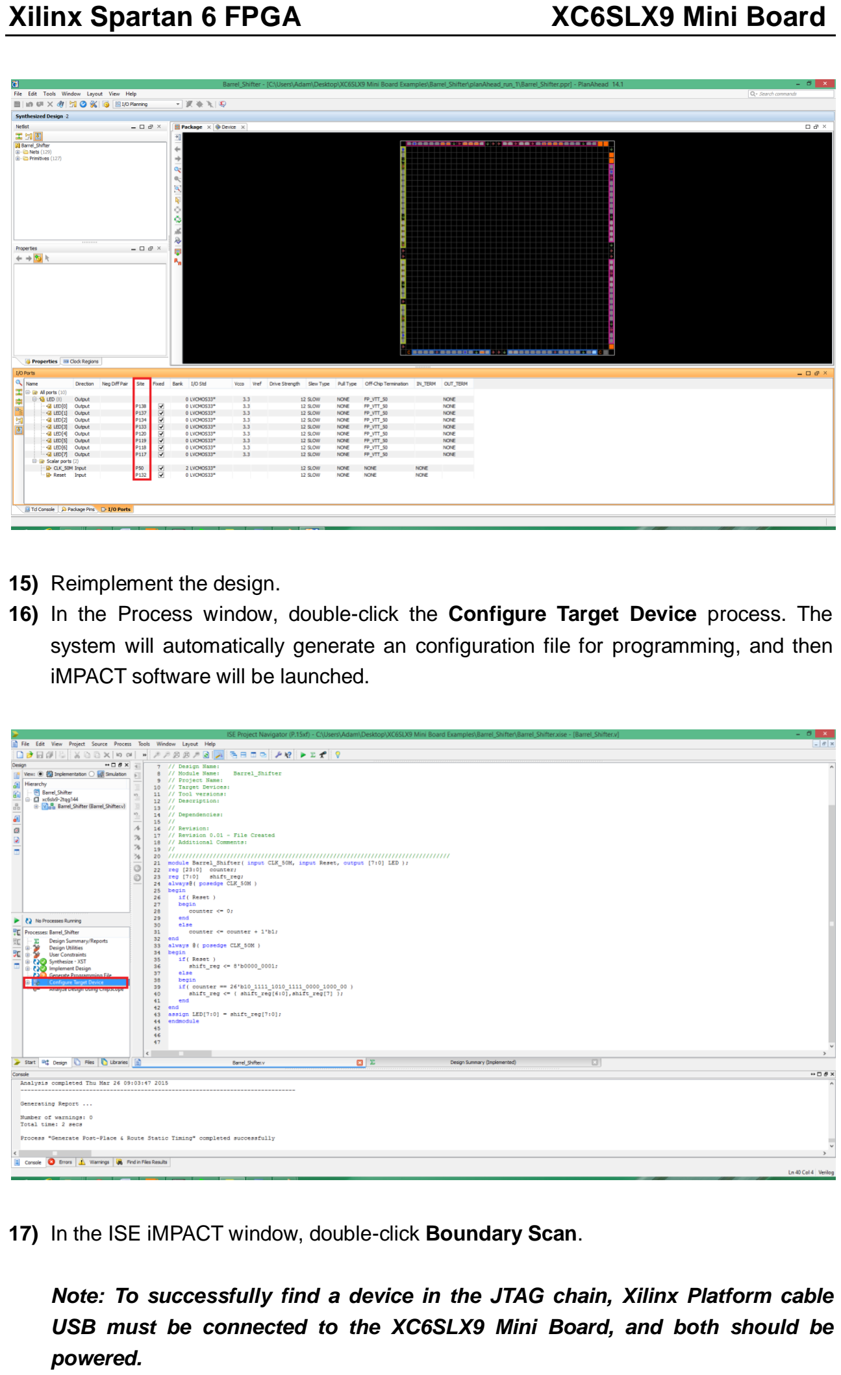
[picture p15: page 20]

15) Reimplement the design.
16) In the Process window, double-click the Configure Target Device process. The system will automatically generate an configuration file for programming, and then iMPACT software will be launched.
17) In the ISE iMPACT window, double-click Boundary Scan.

Note: To successfully find a device in the JTAG chain, Xilinx Platform cable USB must be connected to the XC6SLX9 Mini Board, and both should be powered.

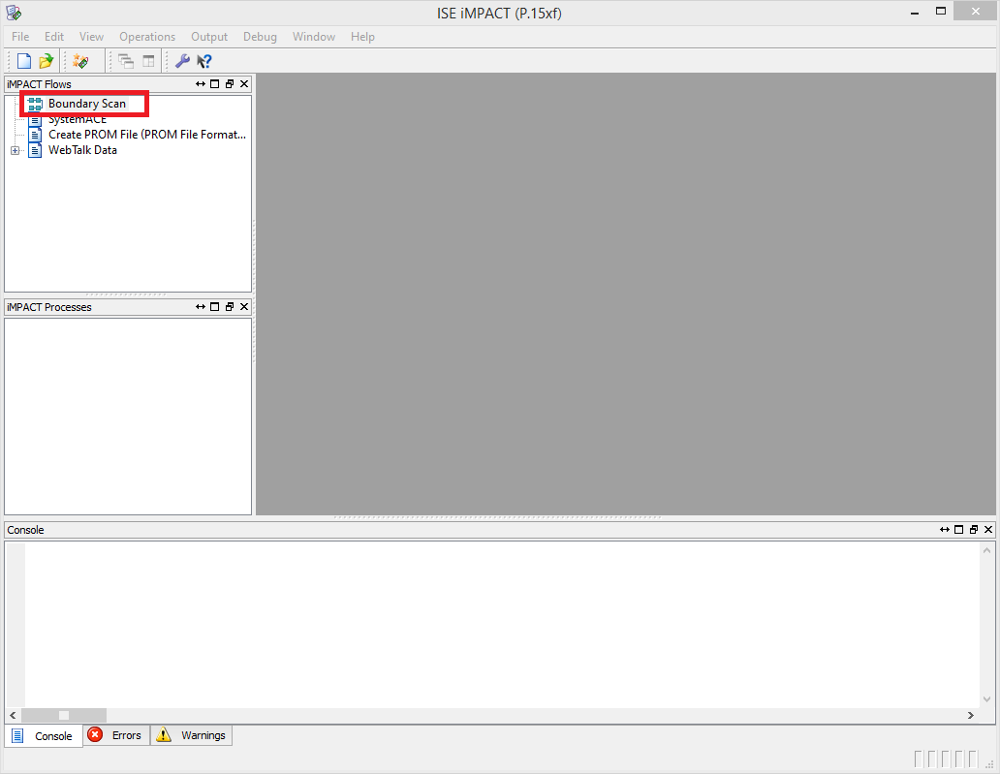
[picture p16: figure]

18) Click the Initialize Chain command, iMPACT will automatically search devices available in the JTAG chain and display the result in the Boundary Scan window.

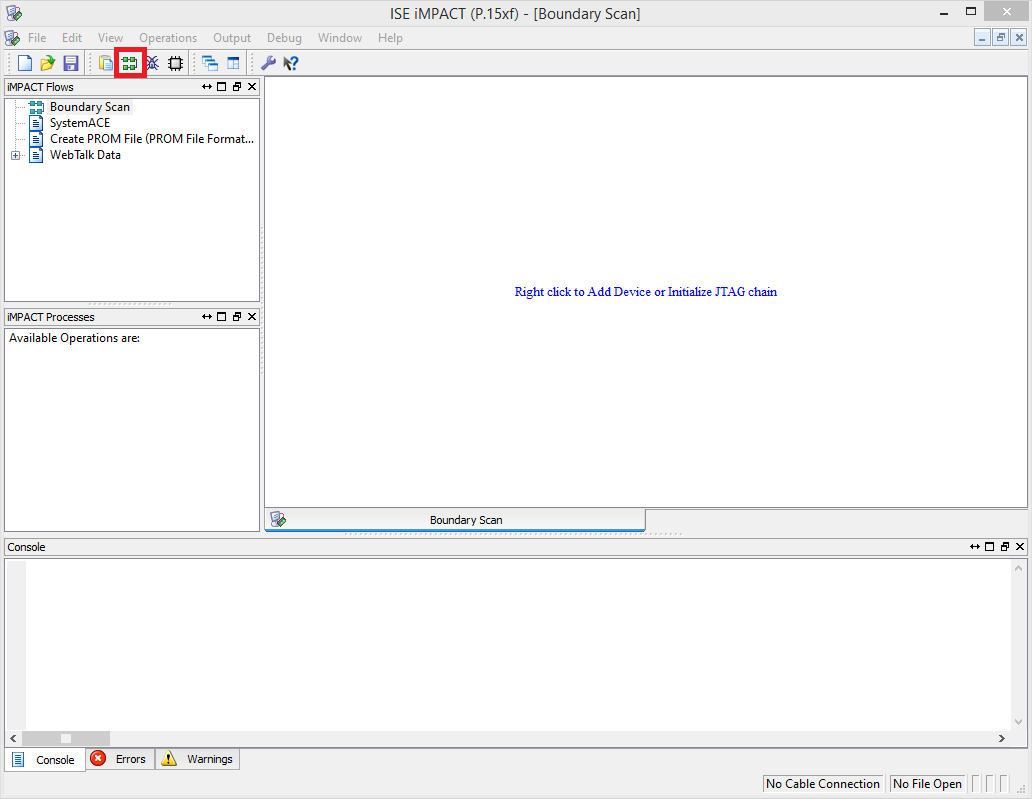
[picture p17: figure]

19) When a device detected, click Yes to assign a configuration file.

20) The generated configuration file is saved under the project directory. Locate the file and click Open to load it into the iMPACT software.

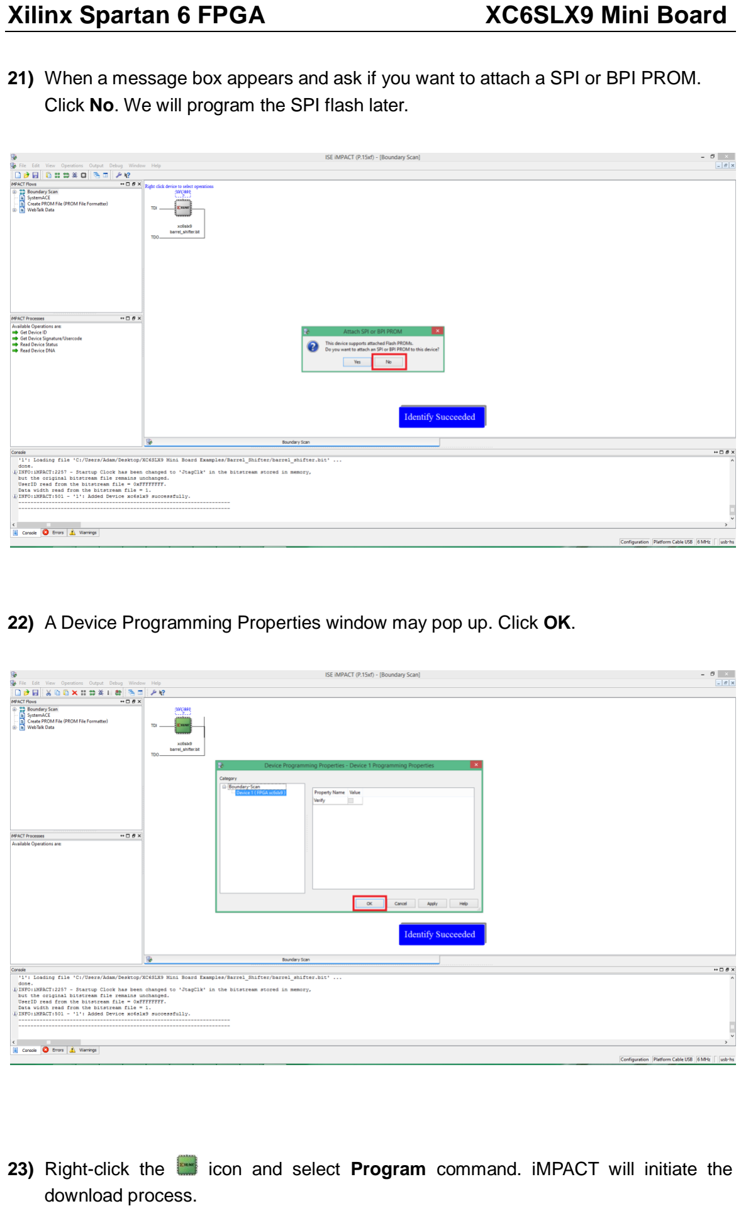
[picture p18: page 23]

21) When a message box appears and ask if you want to attach a SPI or BPI PROM. Click No. We will program the SPI flash later.
22) A Device Programming Properties window may pop up. Click OK.
23) Right-click the icon and select Program command. iMPACT will initiate the download process.

24) When programming is complete, the Program Succeeded message is displayed. Now, you can find only one LED is lit on board and rotating from left to right.

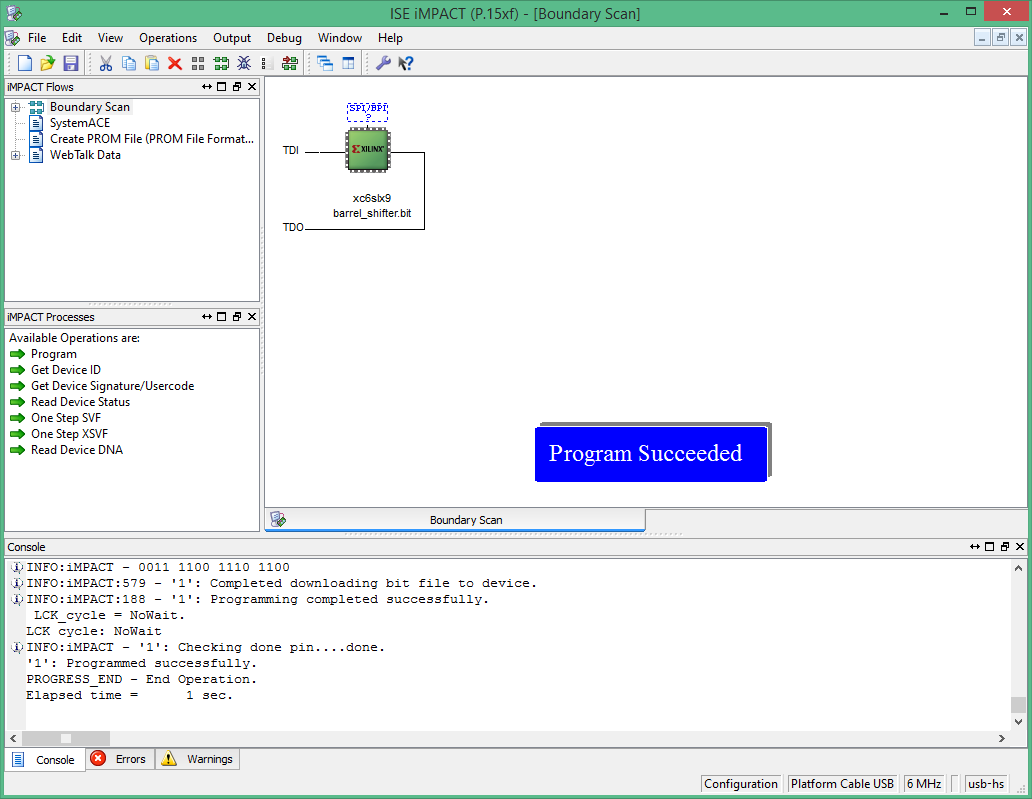
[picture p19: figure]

Note: In the previous steps, the configuration file is downloaded to the SRAM of the target device. As we know, SRAM is a kind of volatile memory, that means data stored in SRAM will be lost when power is removed. The XC6SLX9 Mini Board has a non-volatile SPI flash( W25Q64BV ) to store the configuration file. Data will be automatically loaded into the SRAM of FPGA device during power up. The following steps will show you how to generate a PROM file and program it to the SPI flash.

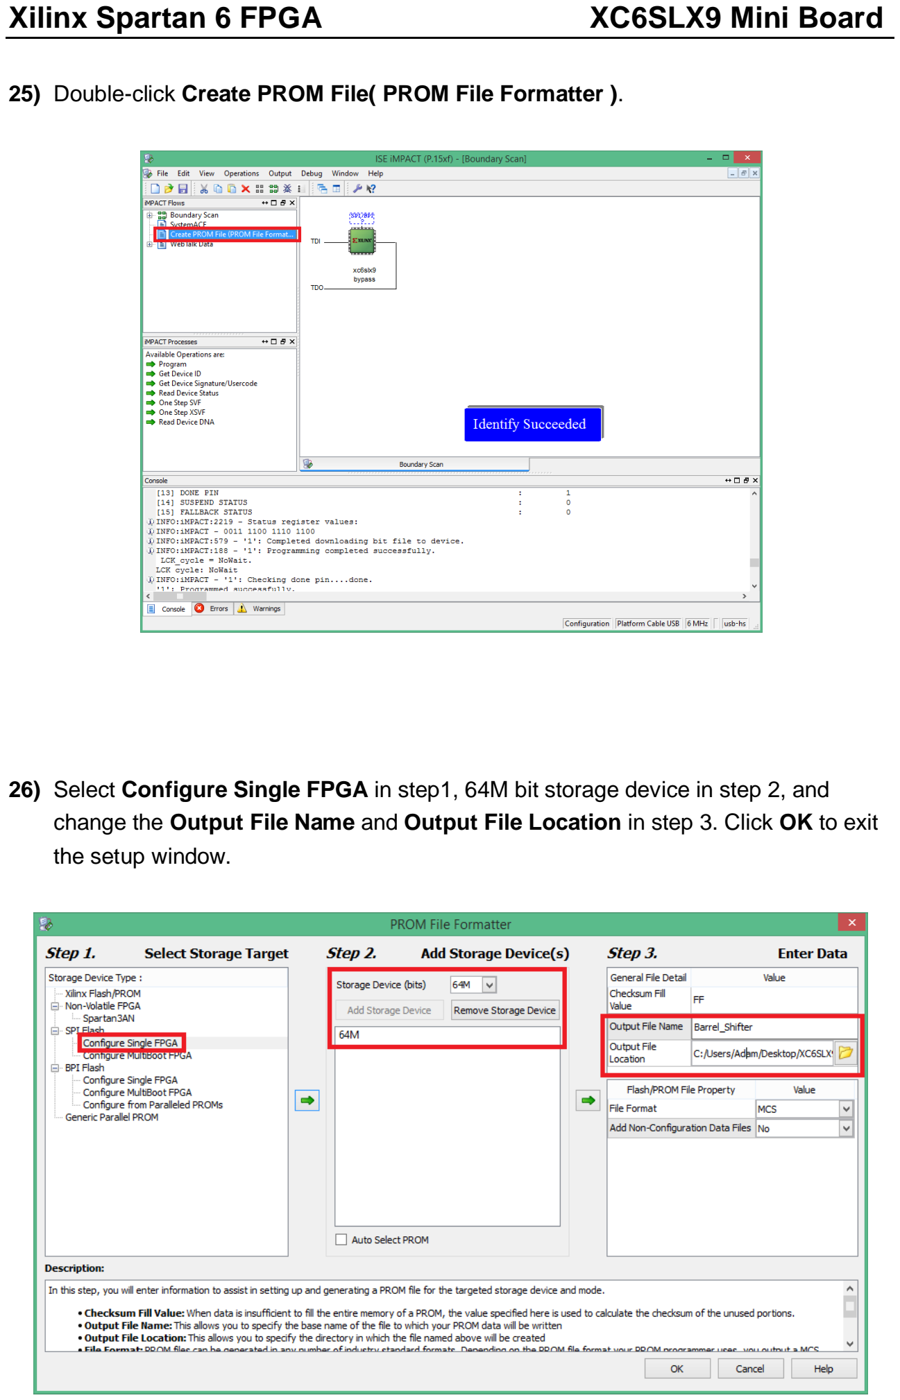
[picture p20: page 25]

25) Double-click Create PROM File( PROM File Formatter ).
26) Select Configure Single FPGA in step1, 64M bit storage device in step 2, and change the Output File Name and Output File Location in step 3. Click OK to exit the setup window.

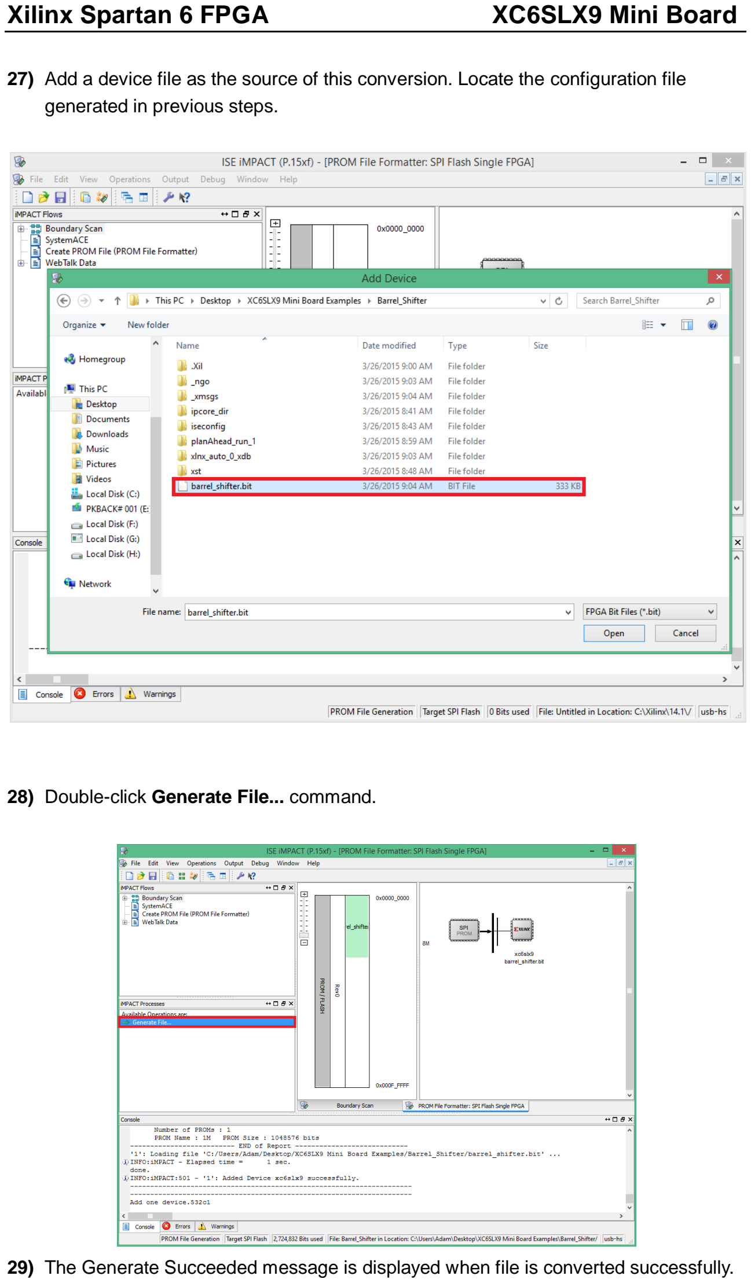
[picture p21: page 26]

27) Add a device file as the source of this conversion. Locate the configuration file generated in previous steps.
28) Double-click Generate File... command.
29) The Generate Succeeded message is displayed when file is converted successfully.

30) Go to the Boundary Scan window and right-click on the icon, select Add SPI/BPI flash... command.
31) Locate the PROM file with .mcs suffix and click Open.

32) Select the SPI PROM(W25Q64BV) and Data Width as shown below. Click OK to exit.
33) Right-click the | icon and select Program command to start programming the

on-board SPI flash.

34) Click OK when Device Programming Properties window appears.
35) Wait patiently while programming the flash.

36) When programming is complete, the Program Succeeded message is displayed.

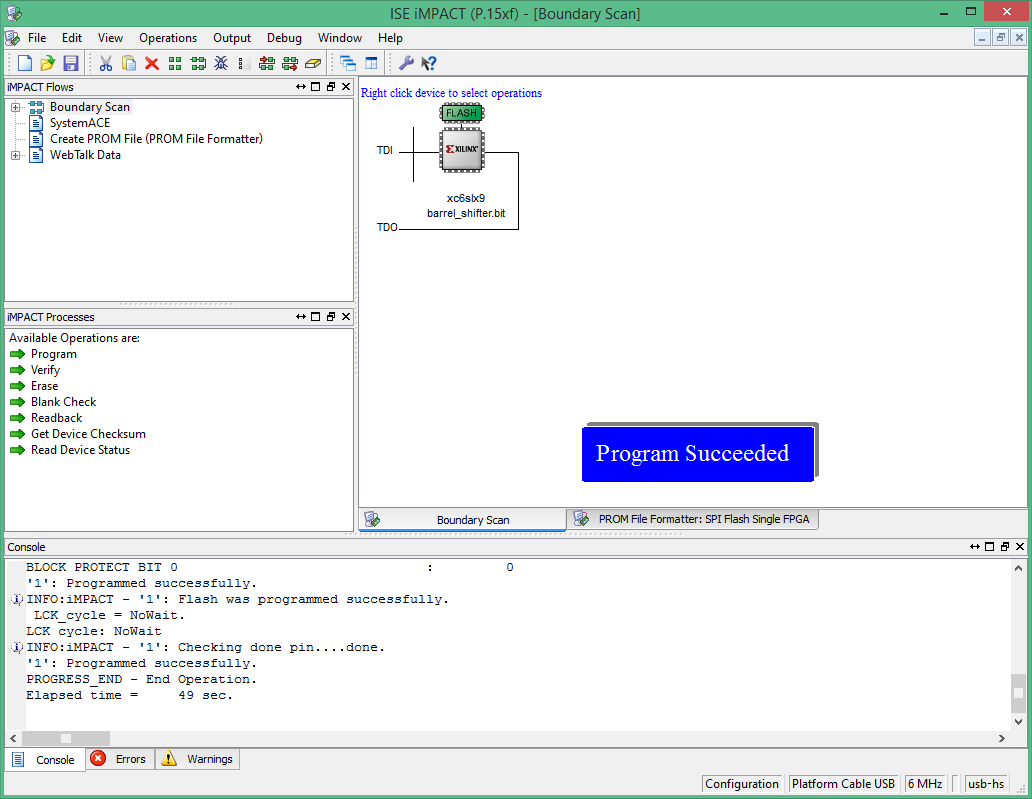
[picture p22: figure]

In this section, we learned the procedure of creating a simple FPGA project and verified it on XC6SLX9 Mini Board. Maybe it's a boring journey. But i really hope you have had a basic understanding of FPGA design using ISE WebPACK. If you want to learn more, please read the help documents and application notes on Xilinx website.

# 4.Hardware

This section describes the hardware peripherals of the XC6SLX9 Mini Board in detail.

## Overview

The XC6SLX9 Mini Board is a pocket-sized platform for Xilinx Spartan 6 FPGA, it includes several basic components to learn digital design on FPGA.

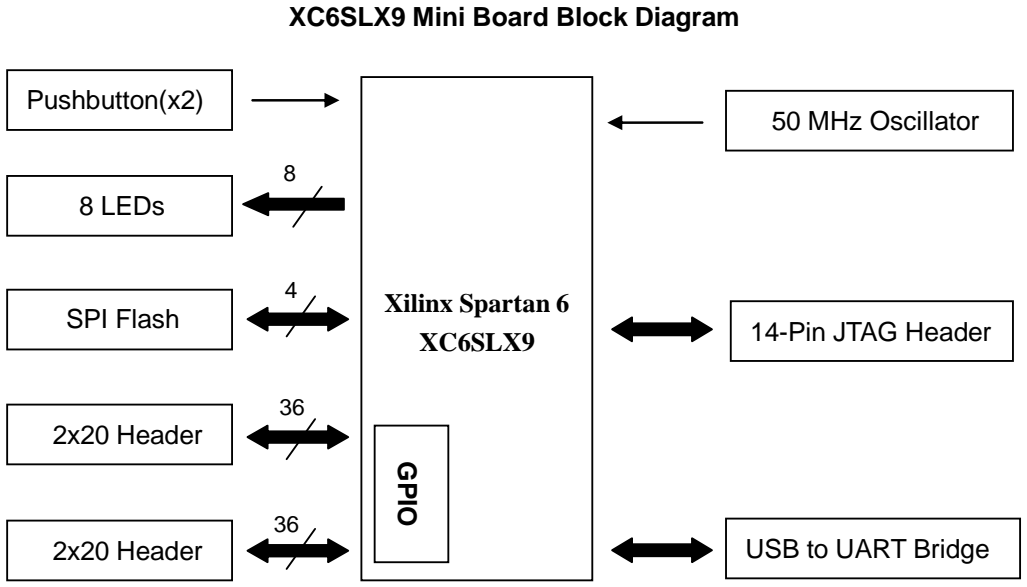
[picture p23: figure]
XC6SLX9 Mini Board Block Diagram; Pushbutton(x2); 50 MHz Oscillator; Xilinx Spartan 6; XC6SLX9; 8 LEDs; SPI Flash; 14-Pin JTAG Header; 2x20 Header; USB to UART Bridge GPIO

## Peripherals and I/O Mapping

- LEDs
Eight LEDs are provided on this board. They are driven directly by the FPGA IOs. Setting one pin to high level lights the LED, and drive the pin low will turn it off. LEDs are usually used as status indicators. Also, eight LEDs can be used to display a 8-bit data.

LED Interface
LED | FPGA Pin Location
LD1 | 138
LD2 | 137
LD3 | 134
LD4 | 133
LD5 | 120
LD6 | 119
LD7 | 118
LD8 | 117
- Switches
The XC6SLX9 Mini Board includes two pushbuttons for user input. Because of the characteristic of mechanical contact switch, glitches will be generated when button is pressed or released. You can implement a debounce circuit on FPGA to filter out the noise. A 200ohm resistor is added to protect IOs from overcurrent damage when pins are set as output in low level. In this case, when button pressed, +3.3V will be shorted to GND via the internal transistor path, and damage the output buffer. In default, the button keeps in low level state, when pressed, it will transit to high level state. Release the button the state will return to low level.

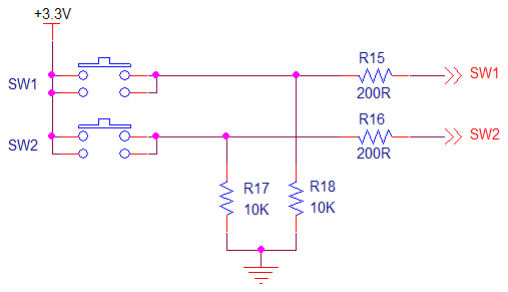
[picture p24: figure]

Switch Interface
Switch | FPGA Pin Number
SW1 | 132
SW2 | 131
- JTAG
The 14-Pin 2.54-Pitch JTAG header can be directly connected with a Xilinx download cable.

JTAG Interface
JTAG Connector Pin Number | JTAG Connector Pin Name | FPGA Pin Number | Pin Functionality
1 | GND | － | GND
2 | +3.3V | － | VCC
3 | GND | － | GND
4 | JTAG_TMS | 107 | TMS
5 | GND | － | GND
6 | JTAG_TCK | 109 | TCK
7 | GND | － | GND
8 | JTAG_TDO | 106 | TDO
9 | GND | － | GND
10 | JTAG_TDI | 110 | TDI
11 | GND | － | GND
12 | － | － | None
13 | GND | － | GND
14 | － | － | None

- Clock Oscillator
Clock is an important element in synchronous digital circuit design. It's often used to synchronize the whole digital system. A 50 MHz oscillator is available on this board. You can use it as a global clock for your design or as a reference clock for internal PLL of FPGA.

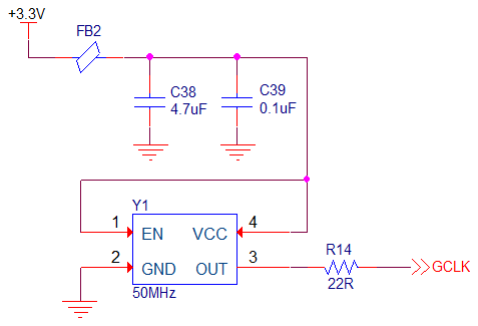
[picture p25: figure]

Clock Oscillator Interface
Clock Oscillator | FPGA Pin Number
Y1 | 50
- USB to UART Bridge
Serial communication can be easily implemented and is widely used when data exchange is needed between PC and peripherals. Since most new generation PCs are not assembled with an older 9-Pin D-Sub serial port. But USB port is abundant. The USB to UART converter IC solves the problem while retaining the advantage of serial port. FT232R is used in this board to play a role of USB to UART converter. When the driver software is properly installed, it will function as a virtual serial port. In addition, two LEDs are used to indicate the status of the TXD and RXD data path. When valid data transfer is detected, the corresponding LED will blink.

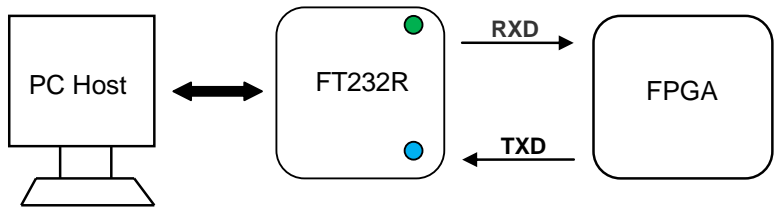
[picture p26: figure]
RXD; TXD; PC Host; FPGA FT232R

UART Interface
UART Signal Name | FPGA Pin Number
FPGA_RX | 47
FPGA_TX | 46

- SPI Flash
The SPI flash on this board is intended to store FPGA configuration file. But it can also be used as a regular SPI flash if you like.

SPI Flash Interface
SPI Flash Signal Name | FPGA Pin Number
CSO | 38
CCLK | 70
MOSI | 64
MISO | 65
- Expansion Header
Two groups of expansion header are available. Each header includes 36 I/Os and +5V, +3.3V power supply. The connector type is a 2x20 0.1" center-to-center, male.

Header－J4 Interface

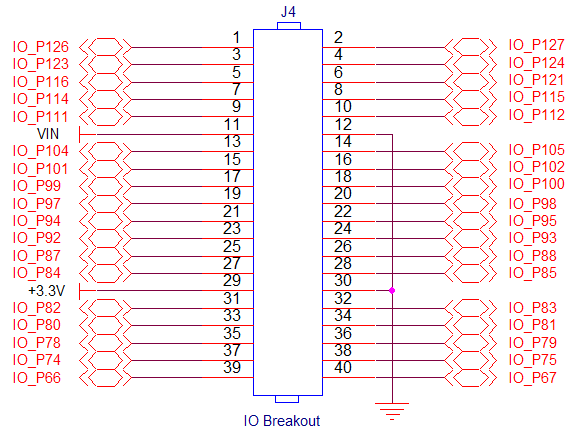
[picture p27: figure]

Expansion Connector Pin number | Expansion Connector Signal Name | FPGA Pin Number | Pin Functionality
1 | IO_P126 | 126 | I/O
2 | IO_P127 | 127 | I/O
3 | IO_P123 | 123 | I/O

4 | IO_P124 | 124 | I/O
5 | IO_P116 | 116 | I/O
6 | IO_P121 | 121 | I/O
7 | IO_P114 | 114 | I/O
8 | IO_P115 | 115 | I/O
9 | IO_P111 | 111 | I/O
10 | IO_P112 | 112 | I/O
11 | VIN | － | Power
12 | GND | － | Ground
13 | IO_P104 | 104 | I/O
14 | IO_P105 | 105 | I/O
15 | IO_P101 | 101 | I/O
16 | IO_P102 | 102 | I/O
17 | IO_P99 | 99 | I/O
18 | IO_P100 | 100 | I/O
19 | IO_P97 | 97 | I/O
20 | IO_P98 | 98 | I/O
21 | IO_P94 | 94 | I/O
22 | IO_P95 | 95 | I/O
23 | IO_P92 | 92 | I/O
24 | IO_P93 | 93 | I/O
25 | IO_P87 | 87 | I/O
26 | IO_P88 | 88 | I/O
27 | IO_P84 | 84 | I/O
28 | IO_P85 | 85 | I/O
29 | +3.3V | － | Power
30 | GND | － | Ground
31 | IO_P82 | 82 | I/O
32 | IO_P83 | 83 | I/O
33 | IO_P80 | 80 | I/O
34 | IO_P81 | 81 | I/O
35 | IO_P78 | 78 | I/O
36 | IO_P79 | 79 | I/O
37 | IO_P74 | 74 | I/O
38 | IO_P75 | 75 | I/O
39 | IO_P66 | 66 | I/O
40 | IO_P67 | 67 | I/O

Header－J5 Interface

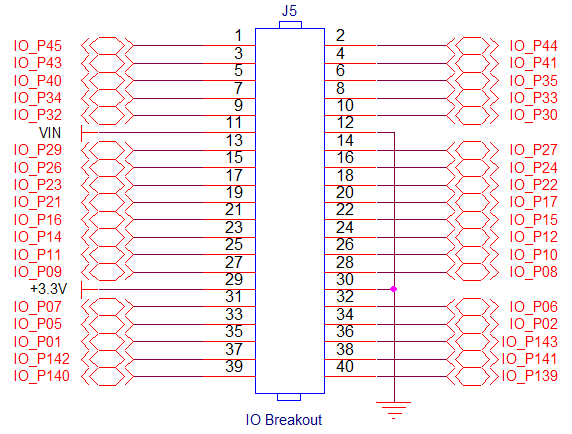
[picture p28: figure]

Expansion Connector Pin number | Expansion Connector Signal Name | FPGA Pin Number | Pin Functionality
1 | IO_P45 | 45 | I/O
2 | IO_P44 | 44 | I/O
3 | IO_P43 | 43 | I/O
4 | IO_P41 | 41 | I/O
5 | IO_P40 | 40 | I/O
6 | IO_P35 | 35 | I/O
7 | IO_P34 | 34 | I/O
8 | IO_P33 | 33 | I/O
9 | IO_P32 | 32 | I/O
10 | IO_P30 | 30 | I/O
11 | VIN | － | Power
12 | GND | － | Ground
13 | IO_P29 | 29 | I/O
14 | IO_P27 | 27 | I/O
15 | IO_P26 | 26 | I/O
16 | IO_P24 | 24 | I/O
17 | IO_P23 | 23 | I/O
18 | IO_P22 | 22 | I/O
19 | IO_P21 | 21 | I/O
20 | IO_P17 | 17 | I/O
21 | IO_P16 | 16 | I/O
22 | IO_P15 | 15 | I/O
23 | IO_P14 | 14 | I/O
24 | IO_P12 | 12 | I/O
25 | IO_P11 | 11 | I/O
26 | IO_P10 | 10 | I/O
27 | IO_P09 | 09 | I/O

28 | IO_P08 | 08 | I/O
29 | +3.3V | － | Power
30 | GND | － | Ground
31 | IO_P07 | 07 | I/O
32 | IO_P06 | 06 | I/O
33 | IO_P05 | 05 | I/O
34 | IO_P02 | 02 | I/O
35 | IO_P01 | 01 | I/O
36 | IO_P143 | 143 | I/O
37 | IO_P142 | 142 | I/O
38 | IO_P141 | 141 | I/O
39 | IO_P140 | 140 | I/O
40 | IO_P139 | 139 | I/O

Revision History
Revision | Date | Note
REV. 0 | 10/1/2014 | Initial release
REV. 1 | 4/1/2015 | Upgrade the on-board SPI flash M25P80 to W25Q64BV.

# Thank You !

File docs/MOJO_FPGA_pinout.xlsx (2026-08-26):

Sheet: Nach FPGA Pin
FPGA UCF P# | SV | SV Pin | Function
1 | SV2 | 34 | IO_L83N_VREF_3
2 | SV2 | 33 | IO_L83P_3
5 | SV2 | 32 | IO_L52N_3
6 | SV2 | 31 | IO_L52P_3
7 | SV2 | 30 | IO_L51N_3
8 | SV2 | 29 | IO_L51P_3
9 | SV2 | 28 | IO_L50N_3
10 | SV2 | 27 | IO_L50P_3
11 | SV2 | 26 | IO_L49N_3
12 | SV2 | 25 | IO_L49P_3
14 | SV2 | 24 | IO_L44N_GCLK20_3
15 | SV2 | 23 | IO_L44P_GCLK21_3
16 | SV2 | 22 | IO_L43N_GCLK22_IRDY2_3
17 | SV2 | 21 | IO_L43P_GCLK23_3
21 | SV2 | 20 | IO_L42N_GCLK24_3
22 | SV2 | 19 | IO_L42P_GCLK25_TRDY2_3
23 | SV2 | 18 | IO_L41N_GCLK26_3
24 | SV2 | 17 | IO_L41P_GCLK27_3
26 | SV2 | 16 | IO_L37N_3
27 | SV2 | 15 | IO_L37P_3
29 | SV2 | 14 | IO_L36N_3
30 | SV2 | 13 | IO_L36P_3
32 | SV2 | 12 | IO_L2N_3
33 | SV2 | 7
33 | SV2 | 11 | IO_L2P_3
34 | SV2 | 8
34 | SV2 | 10 | IO_L1N_VREF_3
35 | SV2 | 9 | IO_L1P_3
37 | PC7 |  | PROGRAM_B_2 | PC7 | PROGRAM_B Active-Low asynchronous full-chip reset, Mojo: AVR PC7
38 | SV1 | 49 | IO_L65N_CSO_B_2 | RESET BTN | Not used in single FPGA applications
39 | PD5 |  | IO_L65P_INIT_B_2 | PD5 | Mojo: AVR PD5
40 | SV2 | 8 | IO_L64N_D9_2
41 | SV2 | 7 | IO_L64P_D8_2
43 | PB1 |  | IO_L62N_D6_2 | PB1 | SelectMAP D6, Mojo: AVR SCKPB1 (!)
44 | PB2 |  | IO_L62P_D5_2 | PB2 | SelectMAP D5, Mojo: AVR MOSI PB2 (!)
45 | PB3 |  | IO_L49N_D4_2 | PB3 | SelectMAP D4, Mojo: AVR MISO PB3 (!)
46 | PB4 |  | IO_L49P_D3_2 | PB4 | SelectMAP D3, Mojo: AVR PB4 (!)
47 |  |  | IO_L48N_RDWR_B_VREF_2 | GND | Determines the direction of the D[x:0] data bus, 0 = inputs, 1 = outputs
48 | PB0 |  | IO_L48P_D7_2 | PB0 | SelectMAP D7, Mojo: AVR SS PB0 (!)
50 | SV2 | 6 | IO_L31N_GCLK30_D15_3
51 | SV2 | 5 | IO_L31P_GCLK31_D14_3
55 |  |  | IO_L30N_GCLK0_USERCCLK_2
56 |  |  | IO_L30P_GCLK1_D13_2
57 |  |  | IO_L14N_D12_2
57 | SV1 | 8 | IO_L14N_D12_2
58 |  |  | IO_L14P_D11_2
58 | SV1 | 7 | IO_L14P_D11_2
59 |  |  | IO_L13N_D10_2
60 |  |  | IO_L13P_M1_2 | VCC3 | M1 M1HI-Pegel = SelectMAP
61 | PB5 |  | IO_L12N_D2_MISO3_2 | PB5 | SelectMAP D2, Mojo: AVR PB5 (!)
62 | PB6 |  | IO_L12P_D1_MISO2_2 | PB6 | SelectMAP D1, Mojo: AVR PB6 (!)
64 |  |  | IO_L3N_MOSI_CSI_B_MISO0_2 | GND | Active-Low chip select to enable the SelectMAP data bus
65 | PB7 |  | IO_L3P_D0_DIN_MISO_MISO1_2 | PB7 | DIN + SelectMAP D0, Mojo: AVR PB7 (!)
66 | SV1 | 10 | IO_L2N_CMPMOSI_2
67 | SV1 | 9 | IO_L2P_CMPCLK_2
69 |  |  | IO_L1N_M0_CMPMISO_2 | GND | M0 LOW-Pegel = SelectMAP
70 | PD0 |  | IO_L1P_CCLK_2 | PD0 | CCLK Configuration clock, Mojo: AVR PD0
71 | SV1 | 6 | DONE_2 |  | DONE1 = FPGA configured,Mojo: AVR PC6
72 |  |  | CMPCS_B_2
73 | SV1 | 5 | SUSPEND
74 | SV1 | 12 | IO_L74N_DOUT_BUSY_1 |  | DOUT This output pin is used during readback.
75 | SV1 | 11 | IO_L74P_AWAKE_1
78 | SV1 | 14 | IO_L47N_1
79 | SV1 | 13 | IO_L47P_1
80 | SV1 | 16 | IO_L46N_1
81 | SV1 | 15 | IO_L46P_1
82 | SV1 | 19 | IO_L45N_1
83 | SV1 | 17 | IO_L45P_1
84 | SV1 | 20 | IO_L43N_GCLK4_1
85 | SV1 | 19 | IO_L43P_GCLK5_1
87 | SV1 | 22 | IO_L42N_GCLK6_TRDY1_1
88 | SV1 | 21 | IO_L42P_GCLK7_1
92 | SV1 | 24 | IO_L41N_GCLK8_1
93 | SV1 | 23 | IO_L41P_GCLK9_IRDY1_1
94 | SV1 | 26 | IO_L40N_GCLK10_1
95 | SV1 | 25 | IO_L40P_GCLK11_1
97 | SV1 | 28 | IO_L34N_1
98 | SV1 | 27 | IO_L34P_1
99 | SV1 | 30 | IO_L33N_1
100 | SV1 | 29 | IO_L33P_1
101 | SV1 | 32 | IO_L32N_1
102 | SV1 | 31 | IO_L32P_1
104 | SV1 | 34 | IO_L1N_VREF_1
105 | SV1 | 33 | IO_L1P_1
106 | SV1 | 46 | TDO
107 | SV1 | 45 | TMS
109 | SV1 | 48 | TCK
110 | SV1 | 47 | TDI
111 | SV1 | 36 | IO_L66N_SCP0_0
112 | SV1 | 35 | IO_L66P_SCP1_0
114 | SV1 | 38 | IO_L65N_SCP2_0
115 | SV1 | 37 | IO_L65P_SCP3_0
116 | SV1 | 40 | IO_L64N_SCP4_0
117 | SV1 | 39 | IO_L64P_SCP5_0
118 | SV1 | 42 | IO_L63N_SCP6_0
119 | SV1 | 41 | IO_L63P_SCP7_0
120 | SV1 | 44 | IO_L62N_VREF_0
121 | SV1 | 43 | IO_L62P_0
123 | SV2 | 50 | IO_L37N_GCLK12_0 | LED 9
124 | SV2 | 49 | IO_L37P_GCLK13_0 | LED 8
126 | SV2 | 48 | IO_L36N_GCLK14_0 | LED 7
127 | SV2 | 47 | IO_L36P_GCLK15_0 | LED 6
131 | SV2 | 46 | IO_L35N_GCLK16_0 | LED 5
132 | SV2 | 45 | IO_L35P_GCLK17_0 | LED 4
133 | SV2 | 44 | IO_L34N_GCLK18_0 | LED 3
134 | SV2 | 43 | IO_L34P_GCLK19_0 | LED 2
137 | SV2 | 42 | IO_L4N_0
138 | SV2 | 41 | IO_L4P_0
139 | SV2 | 40 | IO_L3N_0
140 | SV2 | 39 | IO_L3P_0
141 | SV2 | 38 | IO_L2N_0
142 | SV2 | 37 | IO_L2P_0
143 | SV2 | 36 | IO_L1N_VREF_0
144 | SV2 | 35 | IO_L1P_HSWAPEN_0

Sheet: Nach SV Pin
SV | SV Pin | FPGA UCF Pin | Function | ESP Pin | # MOJO V3 Default UCF
SV1 | 1 |  | GND
SV1 | 2 |  | VCC 5V
SV1 | 3 |  | GND
SV1 | 4 |  | VCC 3V3
SV1 | 5 | P73 | SUSPEND
SV1 | 6 | P71 | DONE_2 |  | ### SV1 Pins ###
SV1 | 7 | P58 | IO_L14P_D11_2 |  | NET "SV1_7" LOC = P58 | IOSTANDARD = LVCMOS33; # IO_L14P_D11_2
SV1 | 8 | P57 | IO_L14N_D12_2 |  | NET "SV1_8" LOC = P57 | IOSTANDARD = LVCMOS33; # IO_L14N_D12_2
SV1 | 9 | P67 | IO_L2P_CMPCLK_2 |  | NET "SV1_9" LOC = P67 | IOSTANDARD = LVCMOS33; # IO_L2P_CMPCLK_2
SV1 | 10 | P66 | IO_L2N_CMPMOSI_2 |  | NET "SV1_10" LOC = P66 | IOSTANDARD = LVCMOS33; # IO_L2N_CMPMOSI_2
SV1 | 11 | P75 | IO_L74P_AWAKE_1 |  | NET "SV1_11" LOC = P75 | IOSTANDARD = LVCMOS33; # IO_L74P_AWAKE_1
SV1 | 12 | P74 | IO_L74N_DOUT_BUSY_1 |  | NET "SV1_12" LOC = P74 | IOSTANDARD = LVCMOS33; # IO_L74N_DOUT_BUSY_1
SV1 | 13 | P79 | IO_L47P_1 |  | NET "SV1_13" LOC = P79 | IOSTANDARD = LVCMOS33; # IO_L47P_1
SV1 | 14 | P78 | IO_L47N_1 |  | NET "SV1_14" LOC = P78 | IOSTANDARD = LVCMOS33; # IO_L47N_1
SV1 | 15 | P81 | IO_L46P_1 |  | NET "SV1_15" LOC = P81 | IOSTANDARD = LVCMOS33; # IO_L46P_1
SV1 | 16 | P80 | IO_L46N_1 |  | NET "SV1_16" LOC = P80 | IOSTANDARD = LVCMOS33; # IO_L46N_1
SV1 | 17 | P83 | IO_L45P_1 |  | NET "SV1_17" LOC = P83 | IOSTANDARD = LVCMOS33; # IO_L45P_1
SV1 | 19 | P85 | IO_L43P_GCLK5_1 |  | NET "SV1_19" LOC = P85 | IOSTANDARD = LVCMOS33; # IO_L43P_GCLK5_1
SV1 | 19 | P82 | IO_L45N_1 |  | NET "SV1_19" LOC = P82 | IOSTANDARD = LVCMOS33; # IO_L45N_1
SV1 | 20 | P84 | IO_L43N_GCLK4_1 |  | NET "SV1_20" LOC = P84 | IOSTANDARD = LVCMOS33; # IO_L43N_GCLK4_1
SV1 | 21 | P88 | IO_L42P_GCLK7_1 |  | NET "SV1_21" LOC = P88 | IOSTANDARD = LVCMOS33; # IO_L42P_GCLK7_1
SV1 | 22 | P87 | IO_L42N_GCLK6_TRDY1_1 | GPIO 15 /SS | NET "SV1_22" LOC = P87 | IOSTANDARD = LVCMOS33; # IO_L42N_GCLK6_TRDY1_1
SV1 | 23 | P93 | IO_L41P_GCLK9_IRDY1_1 | GPIO 13 MOSI | NET "SV1_23" LOC = P93 | IOSTANDARD = LVCMOS33; # IO_L41P_GCLK9_IRDY1_1
SV1 | 24 | P92 | IO_L41N_GCLK8_1 | GPIO 12 MISO | NET "SV1_24" LOC = P92 | IOSTANDARD = LVCMOS33; # IO_L41N_GCLK8_1
SV1 | 25 | P95 | IO_L40P_GCLK11_1 | GPIO 14 SCLK | NET "SV1_25" LOC = P95 | IOSTANDARD = LVCMOS33; # IO_L40P_GCLK11_1
SV1 | 26 | P94 | IO_L40N_GCLK10_1 | GPIO 16 STRB | NET "SV1_26" LOC = P94 | IOSTANDARD = LVCMOS33; # IO_L40N_GCLK10_1
SV1 | 27 | P98 | IO_L34P_1 |  | NET "SV1_27" LOC = P98 | IOSTANDARD = LVCMOS33; # IO_L34P_1
SV1 | 28 | P97 | IO_L34N_1 |  | NET "SV1_28" LOC = P97 | IOSTANDARD = LVCMOS33; # IO_L34N_1
SV1 | 29 | P100 | IO_L33P_1 |  | NET "SV1_29" LOC = P100 | IOSTANDARD = LVCMOS33; # IO_L33P_1
SV1 | 30 | P99 | IO_L33N_1 |  | NET "SV1_30" LOC = P99 | IOSTANDARD = LVCMOS33; # IO_L33N_1
SV1 | 31 | P102 | IO_L32P_1 |  | NET "SV1_31" LOC = P102 | IOSTANDARD = LVCMOS33; # IO_L32P_1
SV1 | 32 | P101 | IO_L32N_1 |  | NET "SV1_32" LOC = P101 | IOSTANDARD = LVCMOS33; # IO_L32N_1
SV1 | 33 | P105 | IO_L1P_1 |  | NET "SV1_33" LOC = P105 | IOSTANDARD = LVCMOS33; # IO_L1P_1
SV1 | 34 | P104 | IO_L1N_VREF_1 |  | NET "SV1_34" LOC = P104 | IOSTANDARD = LVCMOS33; # IO_L1N_VREF_1
SV1 | 35 | P112 | IO_L66P_SCP1_0 |  | NET "SV1_35" LOC = P112 | IOSTANDARD = LVCMOS33; # IO_L66P_SCP1_0
SV1 | 36 | P111 | IO_L66N_SCP0_0 |  | NET "SV1_36" LOC = P111 | IOSTANDARD = LVCMOS33; # IO_L66N_SCP0_0
SV1 | 37 | P115 | IO_L65P_SCP3_0 |  | NET "SV1_37" LOC = P115 | IOSTANDARD = LVCMOS33; # IO_L65P_SCP3_0
SV1 | 38 | P114 | IO_L65N_SCP2_0 |  | NET "SV1_38" LOC = P114 | IOSTANDARD = LVCMOS33; # IO_L65N_SCP2_0
SV1 | 39 | P117 | IO_L64P_SCP5_0 |  | NET "SV1_39" LOC = P117 | IOSTANDARD = LVCMOS33; # IO_L64P_SCP5_0
SV1 | 40 | P116 | IO_L64N_SCP4_0 |  | NET "SV1_40" LOC = P116 | IOSTANDARD = LVCMOS33; # IO_L64N_SCP4_0
SV1 | 41 | P119 | IO_L63P_SCP7_0 |  | NET "SV1_41" LOC = P119 | IOSTANDARD = LVCMOS33; # IO_L63P_SCP7_0
SV1 | 42 | P118 | IO_L63N_SCP6_0 |  | NET "SV1_42" LOC = P118 | IOSTANDARD = LVCMOS33; # IO_L63N_SCP6_0
SV1 | 43 | P121 | IO_L62P_0 |  | NET "SV1_43" LOC = P121 | IOSTANDARD = LVCMOS33; # IO_L62P_0
SV1 | 44 | P120 | IO_L62N_VREF_0 |  | NET "SV1_44" LOC = P120 | IOSTANDARD = LVCMOS33; # IO_L62N_VREF_0
SV1 | 45 | P107 | TMS | GPIO 2
SV1 | 46 | P106 | TDO | GPIO 4
SV1 | 47 | P110 | TDI | GPIO 0
SV1 | 48 | P109 | TCK | GPIO 5
SV1 | 49 | P38 | IO_L65N_CSO_B_2 | RESET BTN
SV1 | 50 |  | GND
SV2 | 1 |  | GND
SV2 | 2 |  | VCC 5V
SV2 | 3 |  | GND
SV2 | 4 |  | VCC 3V3 |  | ### SV2 Pins ###
SV2 | 5 | P31 | IO_L31P_GCLK31_D14_2 |  | NET "SV2_5" LOC = P31 | IOSTANDARD = LVCMOS33; # IO_L31P_GCLK31_D14_2
SV2 | 6 | P50 | IO_L31N_GCLK30_D15_2 |  | NET "SV2_6" LOC = P50 | IOSTANDARD = LVCMOS33; # IO_L31N_GCLK30_D15_2
SV2 | 7 | P41 | IO_L64P_2 |  | NET "SV2_7" LOC = P41 | IOSTANDARD = LVCMOS33; # IO_L64P_2
SV2 | 8 | P40 | IO_L64N_2 |  | NET "SV2_8" LOC = P40 | IOSTANDARD = LVCMOS33; # IO_L64N_2
SV2 | 9 | P35 | IO_L1P_3 |  | NET "SV2_9" LOC = P35 | IOSTANDARD = LVCMOS33; # IO_L1P_3
SV2 | 10 | P34 | IO_L1N_VREF_3 |  | NET "SV2_10" LOC = P34 | IOSTANDARD = LVCMOS33; # IO_L1N_VREF_3
SV2 | 11 | P33 | IO_L2P_3 |  | NET "SV2_11" LOC = P33 | IOSTANDARD = LVCMOS33; # IO_L2P_3
SV2 | 12 | P32 | IO_L2N_3 |  | NET "SV2_12" LOC = P32 | IOSTANDARD = LVCMOS33; # IO_L2N_3
SV2 | 13 | P30 | IO_L36P_3 |  | NET "SV2_13" LOC = P30 | IOSTANDARD = LVCMOS33; # IO_L36P_3
SV2 | 14 | P29 | IO_L36N_3 |  | NET "SV2_14" LOC = P29 | IOSTANDARD = LVCMOS33; # IO_L36N_3
SV2 | 15 | P27 | IO_L37P_3 |  | NET "SV2_15" LOC = P27 | IOSTANDARD = LVCMOS33; # IO_L37P_3
SV2 | 16 | P26 | IO_L37N_3 |  | NET "SV2_16" LOC = P26 | IOSTANDARD = LVCMOS33; # IO_L37N_3
SV2 | 17 | P24 | IO_L41P_GCLK27_3 |  | NET "SV2_17" LOC = P24 | IOSTANDARD = LVCMOS33; # IO_L41P_GCLK27_3
SV2 | 18 | P23 | IO_L41N_GCLK26_3 |  | NET "SV2_18" LOC = P23 | IOSTANDARD = LVCMOS33; # IO_L41N_GCLK26_3
SV2 | 19 | P22 | IO_L42P_GCLK25_TRDY2_3 |  | NET "SV2_19" LOC = P22 | IOSTANDARD = LVCMOS33; # IO_L42P_GCLK25_TRDY2_3
SV2 | 20 | P21 | IO_L42N_GCLK24_3 |  | NET "SV2_20" LOC = P21 | IOSTANDARD = LVCMOS33; # IO_L42N_GCLK24_3
SV2 | 21 | P17 | IO_L43P_GCLK23_3 |  | NET "SV2_21" LOC = P17 | IOSTANDARD = LVCMOS33; # IO_L43P_GCLK23_3
SV2 | 22 | P16 | IO_L43N_GCLK22_IRDY2_3 |  | NET "SV2_22" LOC = P16 | IOSTANDARD = LVCMOS33; # IO_L43N_GCLK22_IRDY2_3
SV2 | 23 | P15 | IO_L44P_GCLK21_3 |  | NET "SV2_23" LOC = P15 | IOSTANDARD = LVCMOS33; # IO_L44P_GCLK21_3
SV2 | 24 | P14 | IO_L44N_GCLK20_3 |  | NET "SV2_24" LOC = P14 | IOSTANDARD = LVCMOS33; # IO_L44N_GCLK20_3
SV2 | 25 | P12 | IO_L49P_3 |  | NET "SV2_25" LOC = P12 | IOSTANDARD = LVCMOS33; # IO_L49P_3
SV2 | 26 | P11 | IO_L49N_3 |  | NET "SV2_26" LOC = P11 | IOSTANDARD = LVCMOS33; # IO_L49N_3
SV2 | 27 | P10 | IO_L50P_3 |  | NET "SV2_27" LOC = P10 | IOSTANDARD = LVCMOS33; # IO_L50P_3
SV2 | 28 | P9 | IO_L50N_3 |  | NET "SV2_28" LOC = P9 | IOSTANDARD = LVCMOS33; # IO_L50N_3
SV2 | 29 | P8 | IO_L51P_3 |  | NET "SV2_29" LOC = P8 | IOSTANDARD = LVCMOS33; # IO_L51P_3
SV2 | 30 | P7 | IO_L51N_3 |  | NET "SV2_30" LOC = P7 | IOSTANDARD = LVCMOS33; # IO_L51N_3
SV2 | 31 | P6 | IO_L52P_3 |  | NET "SV2_31" LOC = P6 | IOSTANDARD = LVCMOS33; # IO_L52P_3
SV2 | 32 | P5 | IO_L52N_3 |  | NET "SV2_32" LOC = P5 | IOSTANDARD = LVCMOS33; # IO_L52N_3
SV2 | 33 | P2 | IO_L83P_3 |  | NET "SV2_33" LOC = P2 | IOSTANDARD = LVCMOS33; # IO_L83P_3
SV2 | 34 | P1 | IO_L83N_VREF_3 |  | NET "SV2_34" LOC = P1 | IOSTANDARD = LVCMOS33; # IO_L83N_VREF_3
SV2 | 35 | P144 | IO_L1P_HSWAPEN_0 |  | NET "SV2_35" LOC = P144 | IOSTANDARD = LVCMOS33; # IO_L1P_HSWAPEN_0
SV2 | 36 | P143 | IO_L1N_VREF_0 |  | NET "SV2_36" LOC = P143 | IOSTANDARD = LVCMOS33; # IO_L1N_VREF_0
SV2 | 37 | P142 | IO_L2P_0 |  | NET "SV2_37" LOC = P142 | IOSTANDARD = LVCMOS33; # IO_L2P_0
SV2 | 38 | P141 | IO_L2N_0 |  | NET "SV2_38" LOC = P141 | IOSTANDARD = LVCMOS33; # IO_L2N_0
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

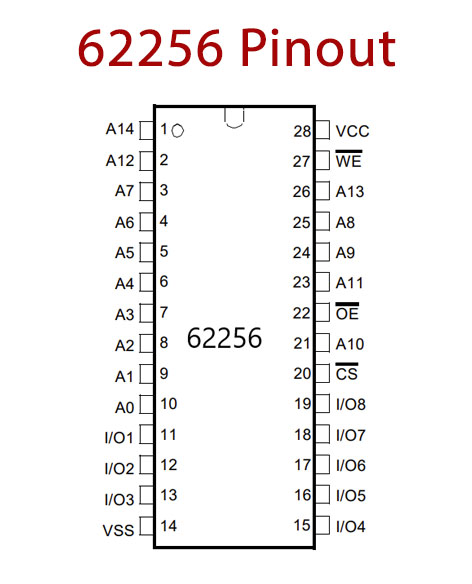
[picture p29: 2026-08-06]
docs/62256-Pinout.jpg

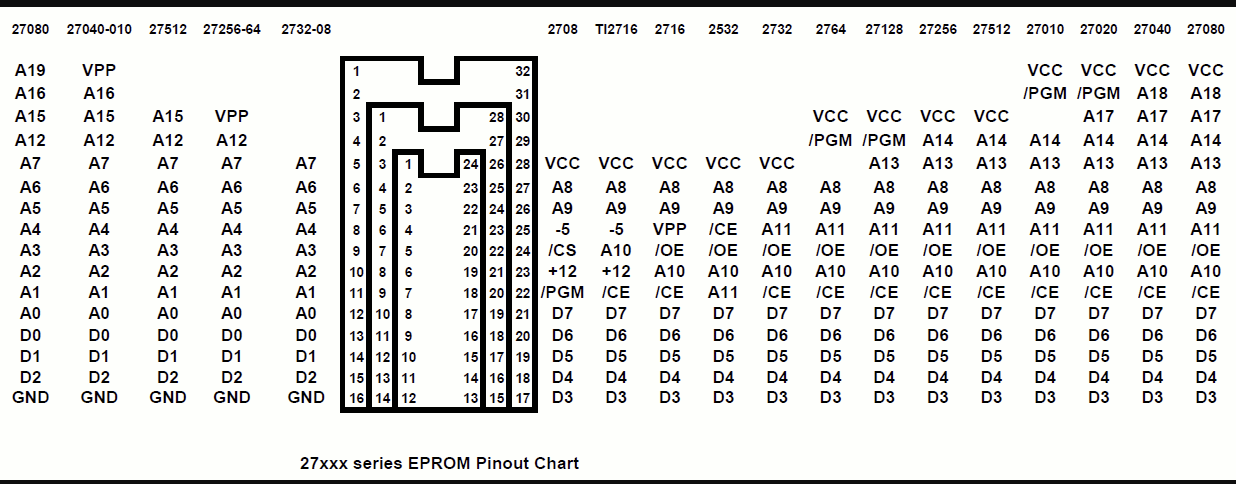
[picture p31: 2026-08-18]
docs/27xxEPROMSeriesPinouts.png.a760bdd71cd3cbc0f7345c0e9d1a7faa.png

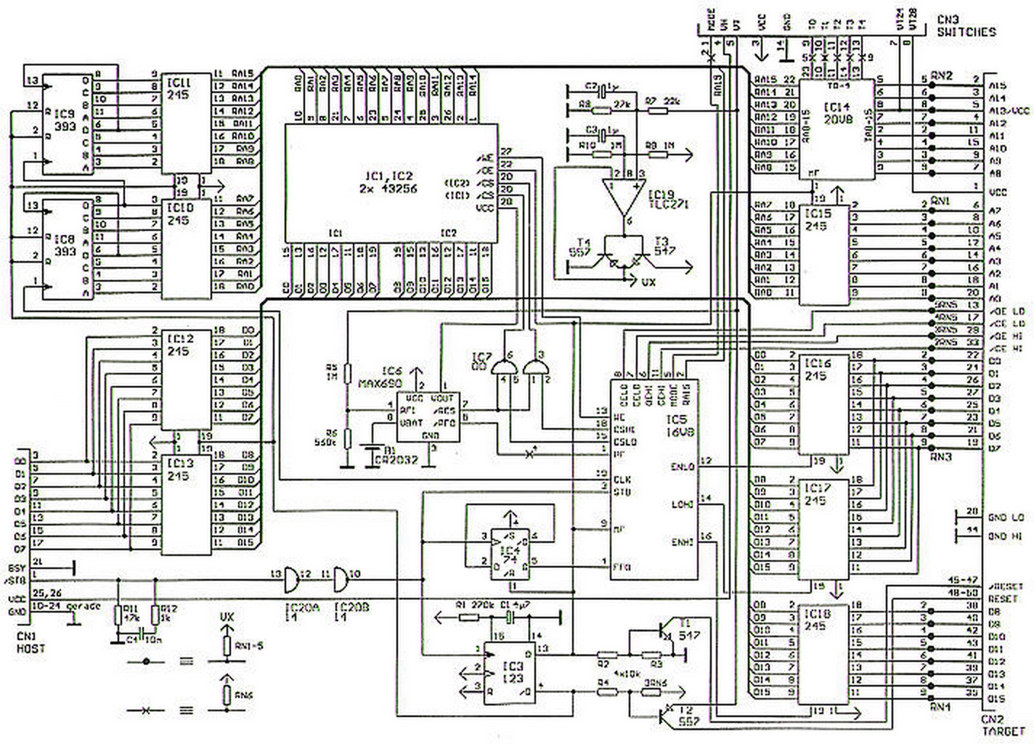
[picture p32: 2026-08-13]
docs/esim/pic03.jpg

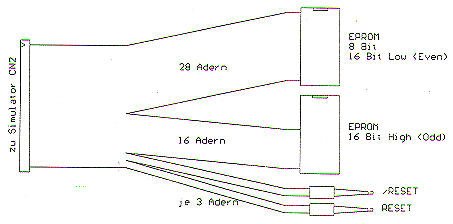
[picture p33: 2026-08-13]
docs/esim/pic05.jpg

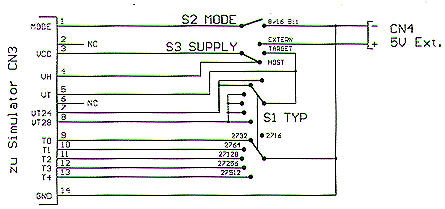
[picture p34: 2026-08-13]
docs/esim/pic06.jpg

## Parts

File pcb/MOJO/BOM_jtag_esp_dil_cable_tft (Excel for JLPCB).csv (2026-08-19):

Comment | Designator | Footprint | LCSC Part #
100n | C1 | 0805_C | C49678
22u 16V | C2 | SMD,D4 | C98746
100n | C3 | 0805_C | C49678
100n | C4 | 0805_C | C49678
100u 16V | C5 | SMD,D6.3 | C37308
1N4148WS | D1 | SOD-323 | C2128
M7 (1A) | D2 | DO-214AA | C95872
M7 (1A) | D3 | DO-214AA | C95872
RED LED | LED1 | 0805 | C84256
470R | R1 | 0805_R | C17710
100R | R2 | 0805_R | C17408
100R | R3 | 0805_R | C17408
100R | R4 | 0805_R | C17408
100R | R5 | 0805_R | C17408
220R | R6 | 0603_x4 | C29719
220R | R7 | 0603_x4 | C29719
220R | R8 | 0603_x4 | C29719
220R | R9 | 0603_x4 | C29719
220R | R10 | 0603_x4 | C29719
220R | R11 | 0603_x4 | C29719
220R | R12 | 0603_x4 | C29719
220R | R13 | 0603_x4 | C29719
220R | R14 | 0603_x4 | C29719
220R | R15 | 0603_x4 | C29719
AMS1117-5.0 | U3 | SOT223 | C6187

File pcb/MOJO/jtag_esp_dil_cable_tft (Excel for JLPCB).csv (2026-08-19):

Name | Value | Package | Place X | Place Y | Rotation
C1 | 100n | SM0805C | 7.30 | 25.40 | 90.00
C2 | 22µ 10V | PANA_B | 46.04 | 6.99 | 270.00
C3 | 100n | SM0805C | 40.32 | 30.48 | 0.00
C4 | 100n | SM0805C | 47.31 | 30.48 | 180.00
C5 | 100µ 25V | PANA_D | 65.41 | 34.61 | 180.00
D1 | 1N4148WS | SOD-323 | 40.50 | 27.94 | 180.00
D2 | M7 (1A) | MLL41 | 53.98 | 36.83 | 270.00
D3 | M7 (1A) | MLL41 | 8.26 | 44.45 | 270.00
LED1 |  | SMD0805 | 19.25 | 5.08 | 0.00
R1 | 470R | SM0805 | 24.13 | 5.08 | 0.00
R2 | 100R | SM0805 | 63.50 | 11.43 | 90.00
R3 | 100R | SM0805 | 65.41 | 11.43 | 90.00
R4 | 100R | SM0805 | 67.31 | 11.43 | 90.00
R5 | 100R | SM0805 | 69.22 | 11.43 | 90.00
R6 | 220R | RN1206 | 20.00 | 52.06 | 0.00
R7 | 220R | RN1206 | 25.08 | 52.06 | 0.00
R8 | 220R | RN1206 | 30.16 | 52.06 | 0.00
R9 | 220R | RN1206 | 35.24 | 52.06 | 0.00
R10 | 220R | RN1206 | 40.32 | 52.06 | 0.00
R11 | 220R | RN1206 | 45.40 | 52.06 | 0.00
R12 | 220R | RN1206 | 50.48 | 52.06 | 0.00
R13 | 220R | RN1206 | 55.56 | 52.06 | 0.00
R14 | 220R | RN1206 | 60.64 | 52.06 | 0.00
R15 | 220R | RN1206 | 65.72 | 52.06 | 0.00
U3 | AMS1117-5.0 | SOT223 | 46.04 | 24.45 | 90.00

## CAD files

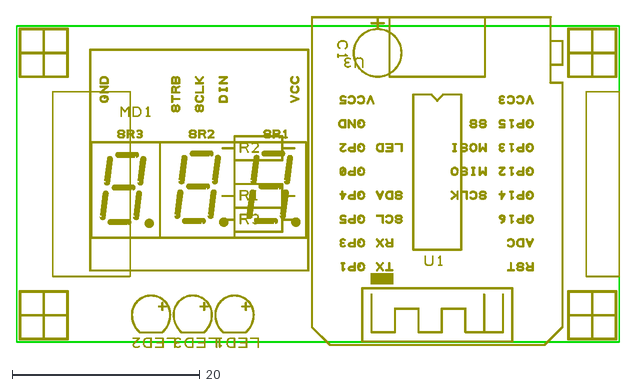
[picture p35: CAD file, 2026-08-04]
pcb/GODIL/godil_esp.dxf
64.3 x 35.3

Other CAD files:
fpga/kcpsm3/picoblaze_test.psm
fpga/kcpsm6/picoblaze_test.psm

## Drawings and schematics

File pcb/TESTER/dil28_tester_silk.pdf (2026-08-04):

# GND VCC

C1

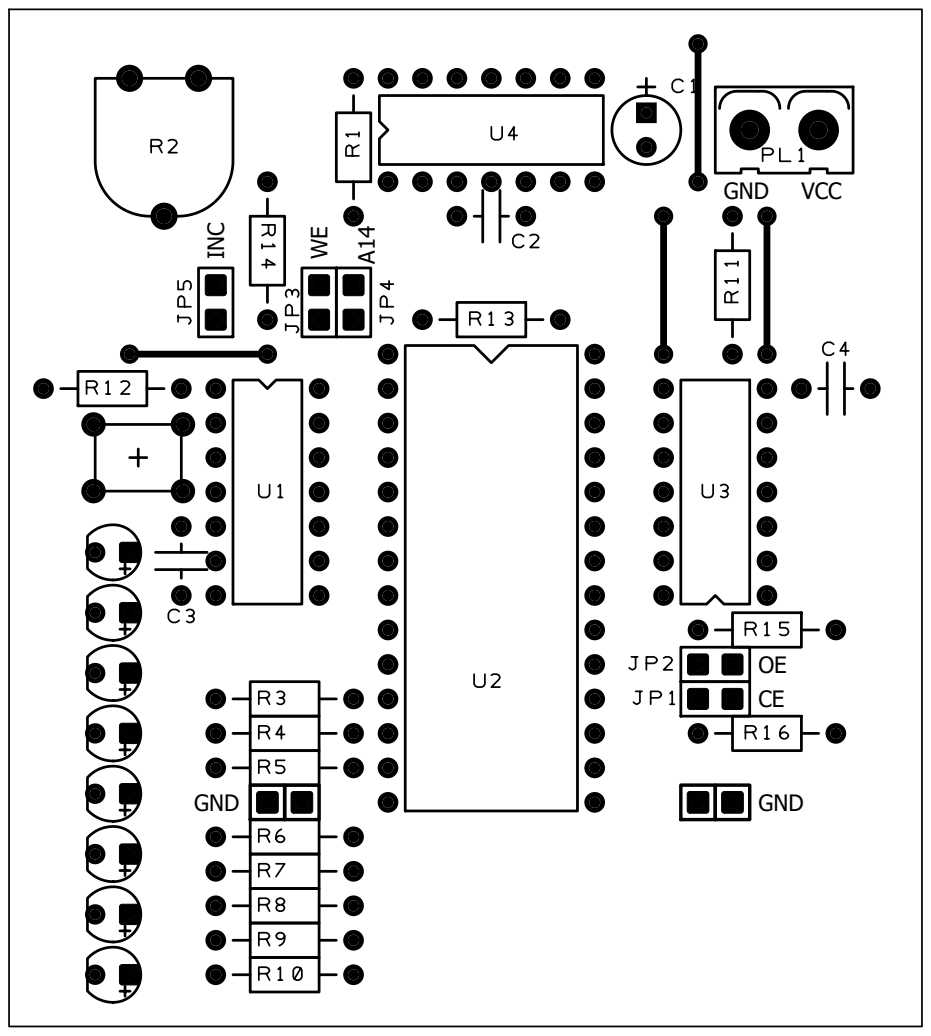
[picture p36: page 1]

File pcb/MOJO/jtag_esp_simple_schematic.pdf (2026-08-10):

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

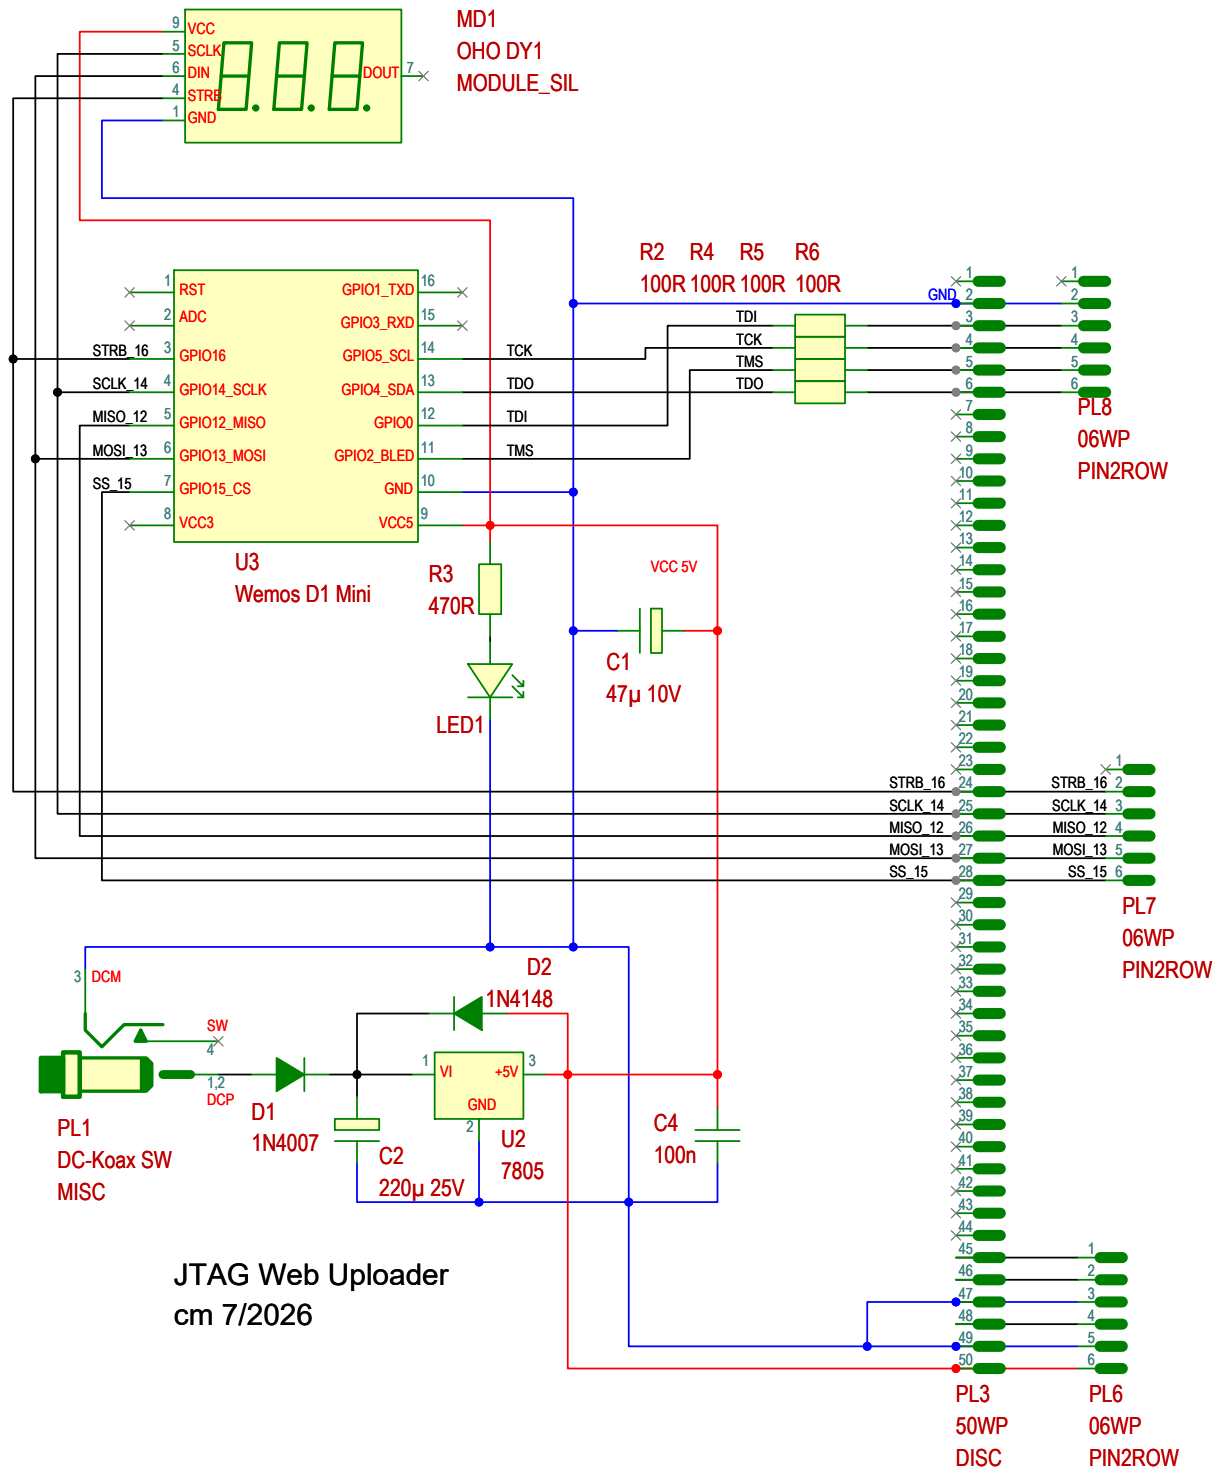
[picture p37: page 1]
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

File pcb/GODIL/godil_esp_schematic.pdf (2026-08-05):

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

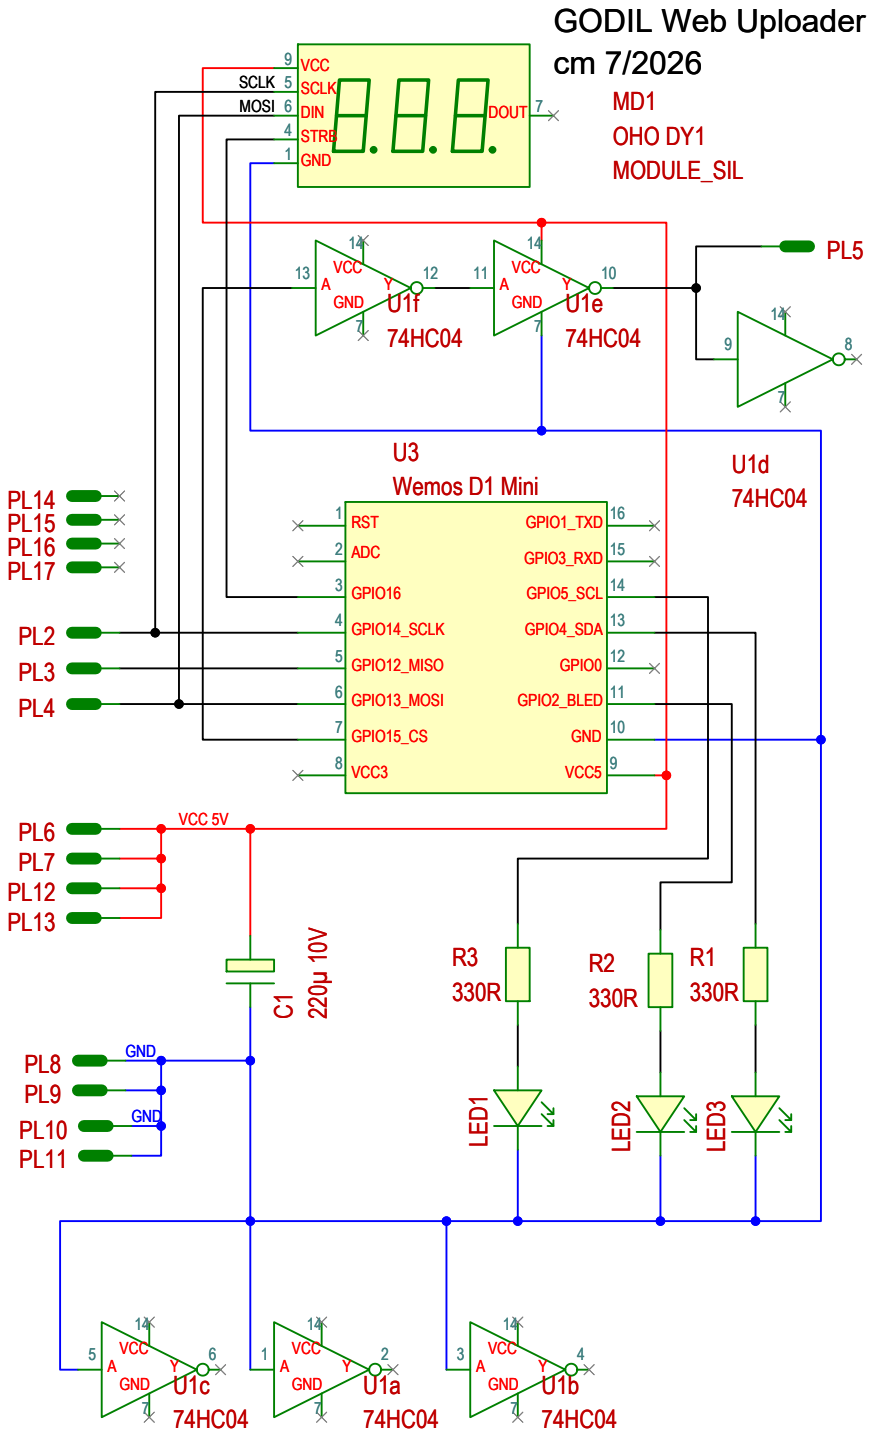
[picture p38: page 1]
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

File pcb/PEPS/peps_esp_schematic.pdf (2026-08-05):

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

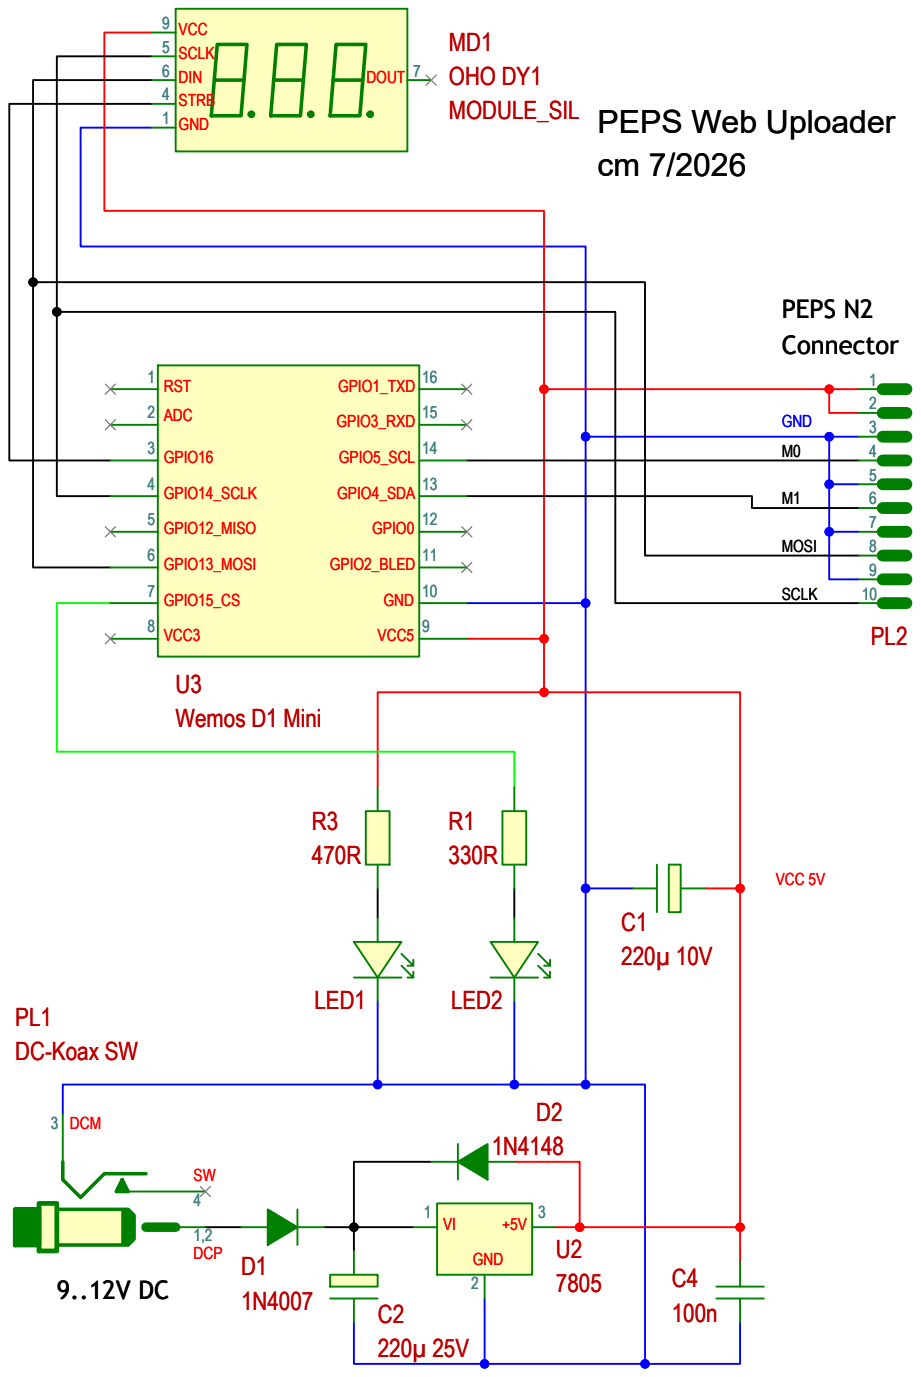
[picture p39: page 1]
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

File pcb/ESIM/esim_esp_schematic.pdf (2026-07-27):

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

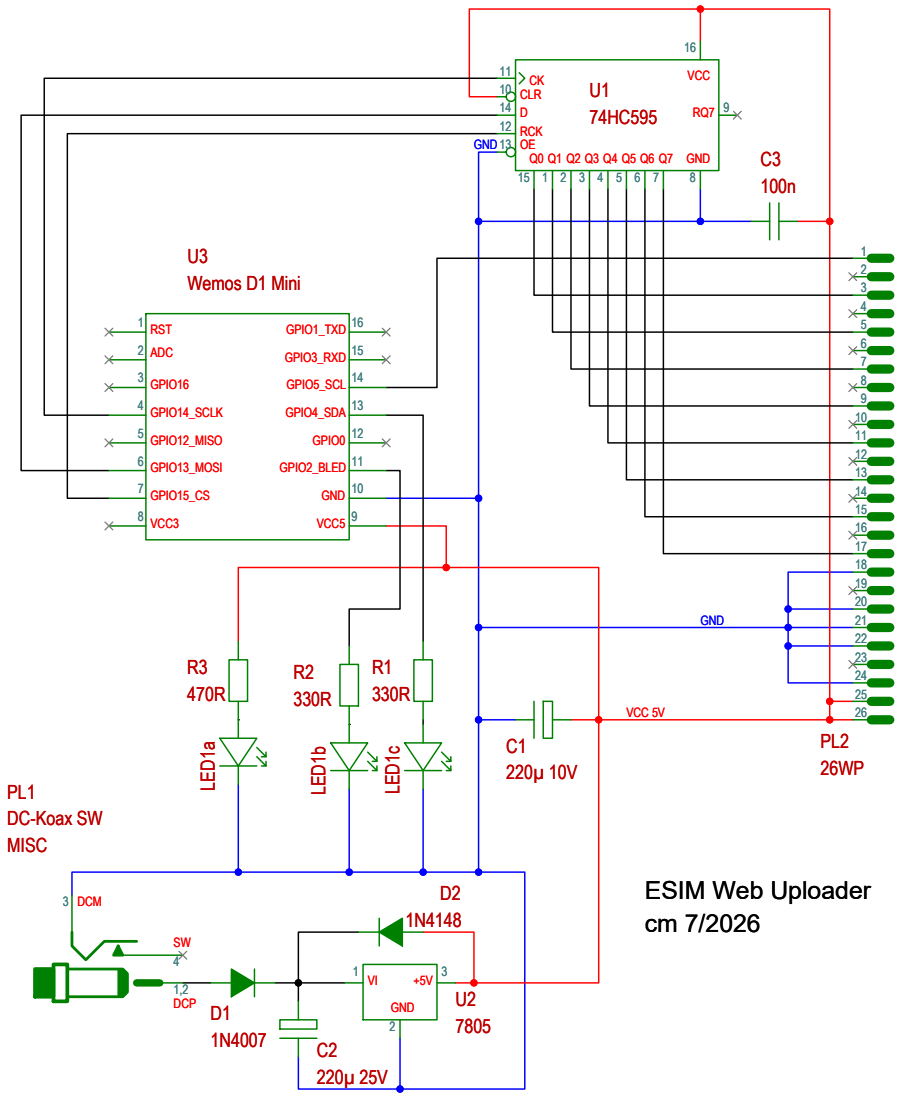
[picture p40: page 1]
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

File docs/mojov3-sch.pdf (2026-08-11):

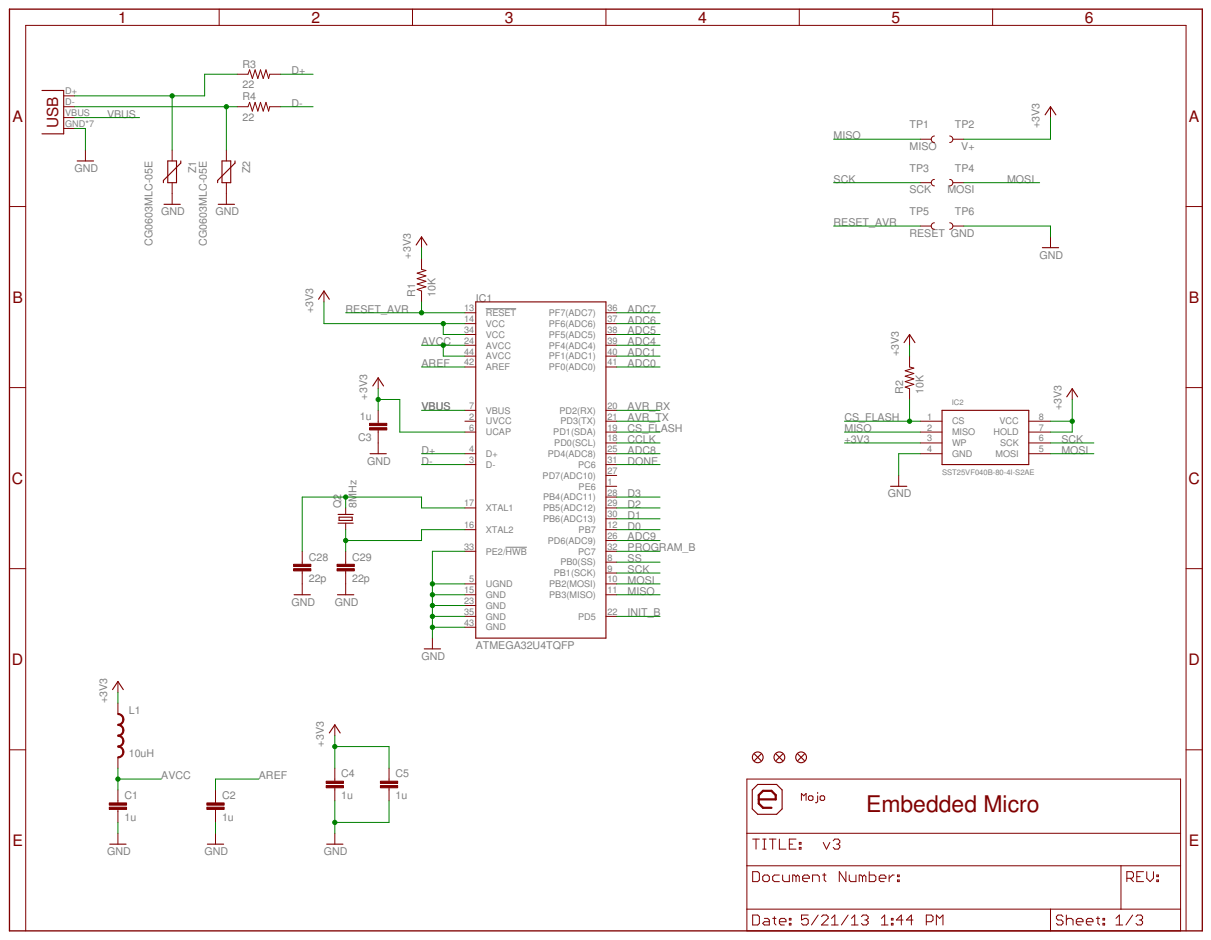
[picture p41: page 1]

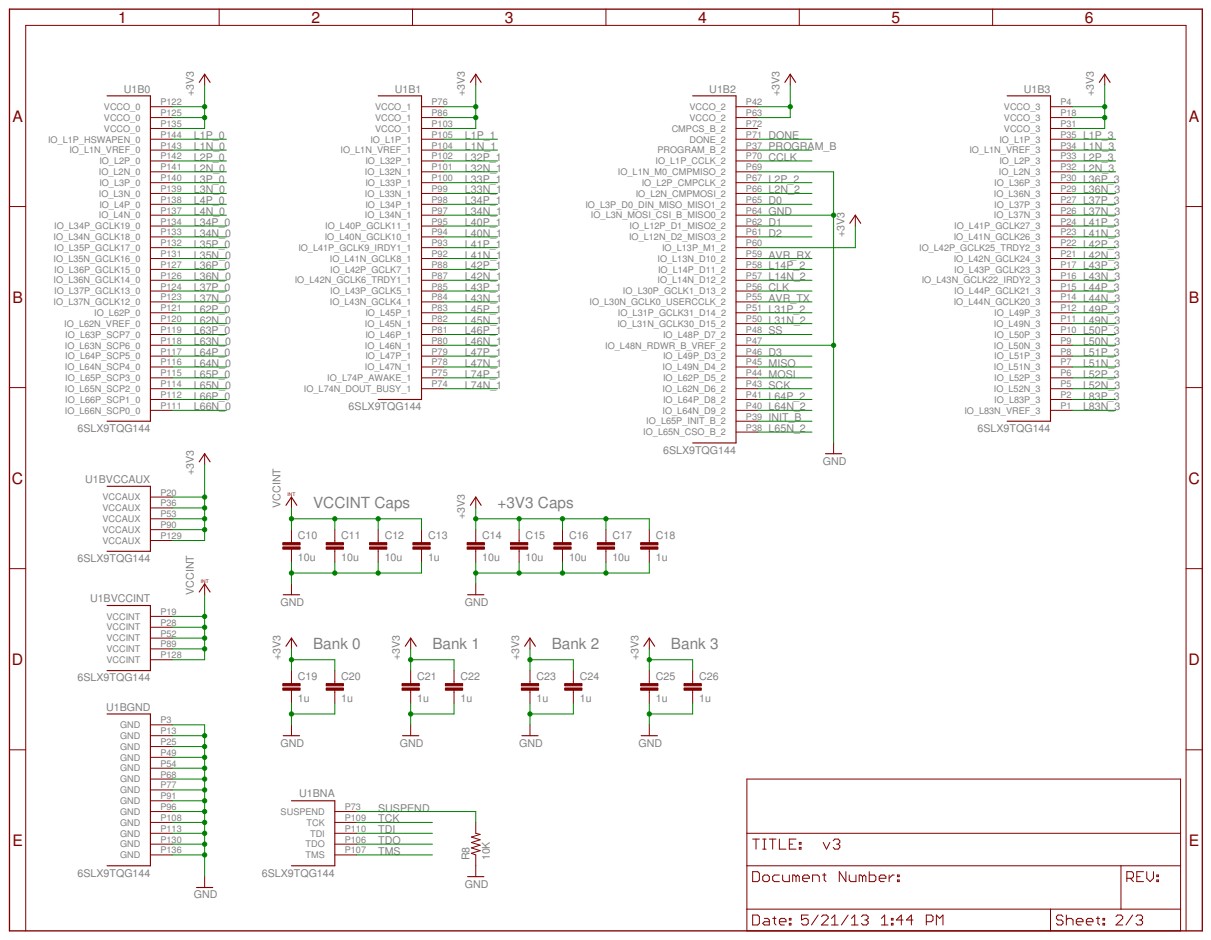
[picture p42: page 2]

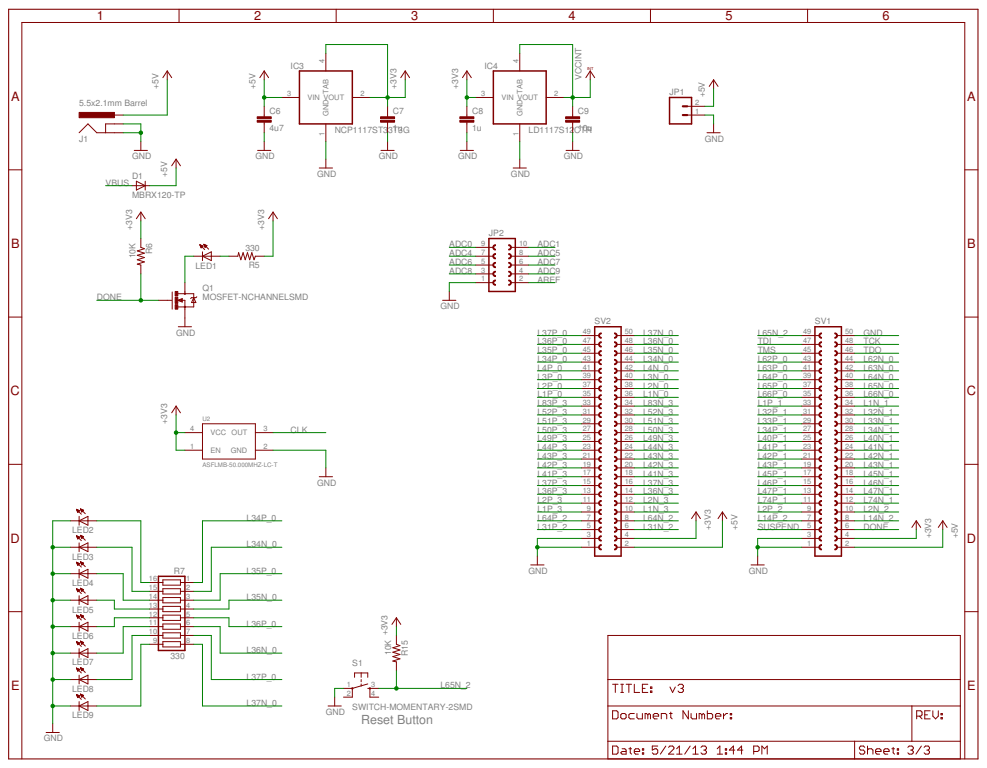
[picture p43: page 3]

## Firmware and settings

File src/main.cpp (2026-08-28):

/*
// ############################################################################
//       __ ________  _____  ____  ___   ___  ___
//      / //_/ __/\ \/ / _ )/ __ \/ _ | / _ \/ _ \
//     / ,< / _/   \  / _  / /_/ / __ |/ , _/ // /
//    /_/|_/___/_  /_/____/\____/_/_|_/_/|_/____/
//      / _ \/ _ | / _ \/_  __/ |/ / __/ _ \
//     / ___/ __ |/ , _/ / / /    / _// , _/
//    /_/  /_/ |_/_/|_| /_/ /_/|_/___/_/|_|
//
// ############################################################################
*/

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
// Created with massive help from ChatGPT 5.3 CODEX

// Upload a binary file to the ESP8266 over Wi-Fi and stream its bytes to a 74HC595 shift register using SPI
// (LSB first, 8-bit parallel output, with a strobe signal to latch the outputs).
// Useful for EPROM simulators loaded by a Centronics-like parallel interface,
// or other applications that require streaming bytes to a shift register.

// 74HC595 SER (DS) to MOSI (GPIO13 / D7), SRCLK (SH_CP) to SCLK (GPIO14 / D5).
// RCLK (ST_CP latch) uses GPIO 5 (D1). Tie /OE low and /SRCLR high for always-enabled output.

// Serial commands: e=erase EPROM, r=replay staged file, c=cancel streaming, i=print info,
// n=next serial upload filename terminated by CR,
// u=lenLo,lenHi,data... upload payload by serial (LE length, timeout-protected),
// d=filename,start,len<CR> dumps EPROM bytes to LittleFS,
// j=hexdump 1024 bytes from inputByte() as 16-byte rows.

// The associated sending app ESIM.EXE uses the following protocol:
// Upload flow in main is now:
// Send u command + 16-bit length word.
// Wait for ACK (1 second timeout).
// Send data in chunks of 128 bytes (last chunk can be smaller).
// After each chunk, wait for ACK (1 second timeout).
// Compute 16-bit checksum (sum of all data bytes modulo 65536).
// Send checksum as 16-bit word LSB first.
// Wait for final ACK (1 second timeout).
// On any timeout or NAK, the app exits with an explicit error message indicating at which stage ACK timed out.
// Added waitForAck(...) with a 1-second timeout per wait.
// Waits for ASCII ACK byte 0x06.
// Returns error on timeout or read failure.
// Still prints incoming text lines and tracks ERROR: messages while waiting.

#include <Arduino.h>
#include <ESP8266WebServer.h>
#include <ESP8266WiFi.h>
#include <LittleFS.h>
#include <SPI.h>
#include <cstdlib>
#include <cstdio>
#include "global_vars.h" // for #defines
#include "jtag_send.h"

// Display helpers are extracted to a dedicated header.
#include "dy1_display.h"

#ifdef USE_TFT_DISPLAY
  #include <TFT_eSPI.h>
#endif

ESP8266WebServer server(80);


String htmlEscape(const String &input);
String urlEncodeComponent(const String &input);
bool startPlaybackFromStaging(uint32_t startAddr, const String &filePath);
bool parseUnsignedValue(const String &text, uint32_t &valueOut);
bool loadStartAddressForFile(const String &filePath, uint32_t &startAddrOut);
bool loadGlobalSettings();
bool saveGlobalSettings();
bool isNonStreamableFilePath(const String &path);

uint32_t resolveStartAddressForPath(const String &path) {
  uint32_t startAddr = 0;
  if (path.length() > 0) {
    loadStartAddressForFile(path, startAddr);
  }
  return startAddr;
}

// SPI transfer and device I/O helpers are extracted to a dedicated header.
#include "spi_transfer.h"
// SERVER & WEB PAGES
#include "web_server_funcs.h"
// Serial command handlers and parsing helpers are extracted into a dedicated header.
#include "serial_cmd.h"
// Playback staged files
#include "playback.h"

// ##############################################################################
//
//      #####  ####### ####### #     # ######  
//     #     # #          #    #     # #     # 
//     #       #          #    #     # #     # 
//      #####  #####      #    #     # ######  
//           # #          #    #     # #       
//     #     # #          #    #     # #       
//      #####  #######    #     #####  #       
//                                             
// ##############################################################################
// MAIN SETUP AND LOOP
// ##############################################################################

// Initializes serial, SPI, filesystem, Wi-Fi, and web server routes.
void setup() {
  Serial.begin(115200);
  delay(100);

  Serial.println();

  pinMode(LED_BUILTIN, OUTPUT);
  digitalWrite(LED_BUILTIN, LOW);
  delay(200);
  digitalWrite(LED_BUILTIN, HIGH);
  delay(200);
  digitalWrite(LED_BUILTIN, LOW);
  delay(200);
  
  #ifndef JTAG_SPARTAN6
    pinMode(LED_SENDDATA, OUTPUT);
    digitalWrite(LED_SENDDATA, LOW);
  #endif

  #ifdef JTAG_SPARTAN6
    pinMode(LATCH_PIN, OUTPUT);
    digitalWrite(LATCH_PIN, HIGH);
    Serial.print(F("FPGA Binary Uploader by Carsten Meyer 7/2026 V. "));
    Serial.println(versionString);
    SPI.begin();
    SPI.setFrequency(10000000);
    SPI.setDataMode(SPI_MODE0);
    SPI.setBitOrder(MSBFIRST);
  #endif

  #ifdef GODIL_SPI
    pinMode(LED_UPLOAD, OUTPUT);
    digitalWrite(LED_UPLOAD, LOW);
    pinMode(LATCH_PIN, OUTPUT);
    digitalWrite(LATCH_PIN, HIGH);
    Serial.print(F("GODIL Binary Uploader by Carsten Meyer 7/2026 V. "));
    Serial.println(versionString);
    SPI.begin();
    SPI.setFrequency(10000000);
    SPI.setDataMode(SPI_MODE0);
    SPI.setBitOrder(MSBFIRST);
  #endif

  #ifdef ESIM_SPI
    pinMode(LATCH_PIN, OUTPUT);
    digitalWrite(LATCH_PIN, HIGH);
    pinMode(STROBE_PIN, OUTPUT);
    digitalWrite(STROBE_PIN, HIGH); 
    Serial.print(F("ESIM Binary Uploader by Carsten Meyer 7/2026 V. "));
    Serial.println(versionString);
    SPI.begin();
    SPI.setFrequency(10000000);
    SPI.setDataMode(SPI_MODE0);
    SPI.setBitOrder(MSBFIRST);
  #endif

  #ifdef PEPS_SPI
    pinMode(LATCH_CLK, OUTPUT);
    digitalWrite(LATCH_CLK, LOW);
    pinMode(DATA_PIN, OUTPUT);
    digitalWrite(DATA_PIN, LOW);
    pinMode(M0_PIN, OUTPUT);
    digitalWrite(M0_PIN, HIGH);
    pinMode(M1_PIN, OUTPUT);
    digitalWrite(M1_PIN, HIGH);
    Serial.print(F("PEPS Binary Uploader by Carsten Meyer 7/2026 V. "));
    Serial.println(versionString);
    SPI.begin();
    SPI.setFrequency(4000000);
    SPI.setDataMode(SPI_MODE0);
    SPI.setBitOrder(MSBFIRST);
  #endif

  #ifdef USE_DY1_DISPLAY
    clear_disp(0);
    pinMode(DY1_LATCH_PIN, OUTPUT);
    digitalWrite(DY1_LATCH_PIN, LOW);
    dy1message(F("rst"));
  #endif

  #ifdef USE_TFT_DISPLAY
    pinMode(TFT_CS, OUTPUT);
    pinMode(TFT_DC, OUTPUT);
    tft.init();
    tft.setRotation(3);  //The parameters are: 0, 1, 2, 3, representing the rotation of the screen 0°, 90°, 180°, 270°
    tft.setTextSize(1);
    tft.fillRect(0, 0, 160, 160, TFT_BLACK);
    drawStringBox(F("ESP Uploader"), "Version " + String(versionString));
    delay(500);
  #endif

  if (!LittleFS.begin()) {
    Serial.println(F("ERROR: LittleFS init failed"));
    fsMounted = false;
    dy1message(F("FsE"));
    drawMsgBox(F("Error"), F("LittleFS init failed"), DB_ERROR);
  } else {
    fsMounted = true;
    loadGlobalSettings();
    if (lastFilename.length() > 0) {
      const String restoredPath = normalizeFsPath(lastFilename);
      if (isValidFsPath(restoredPath) && LittleFS.exists(restoredPath)) {
        currentFilePath = restoredPath;
      }
    }
    if (currentFilePath.length() > 0 && LittleFS.exists(currentFilePath)) {
      File restoreFile = LittleFS.open(currentFilePath, "r");
      if (restoreFile) {
        stagedFileBytes = restoreFile.size();
        lastFileBytes = stagedFileBytes;
        lastFilename = baseNameFromPath(currentFilePath);
        restoreFile.close();
      }
    }
  }

  #ifdef GODIL_SPI
    fpgaValid = true;  
    getFPGAversion();
  #endif

  #ifdef JTAG_SPARTAN6
    if (fsMounted) {
      if (LittleFS.exists(startupFpgaPath) && isBitstreamFilePath(startupFpgaPath)) {
        drawStringBox(F("FPGA Config"), startupFpgaPath);
        dy1message(F("cfg"));
        if (jtagCheckIDcode()) {
          jtagConfigure(startupFpgaPath);
          printIDcode();
        }
      } else {
        dy1message(F("Err"));
        drawMsgBox(F("FPGA File"), F("not found!"), DB_ERROR);
        Serial.print(F("File "));
        Serial.print(startupFpgaPath);
        Serial.println(F(" not found, FPGA not configured!"));
      }
    }
  #endif

  if (autoplayEnabled && !isBitstreamFilePath(currentFilePath)) {
    startPlaybackFromStaging(resolveStartAddressForPath(currentFilePath), currentFilePath);
  }

  #if defined(GODIL_SPI) || defined(JTAG_SPARTAN6)
    outputChipType(currentChipTypeIndex);
    outputPort(0, port0value); // set all outputs
    outputPort(1, port1value); // set all outputs
  #endif
  
  #ifdef USE_WEB_SERVER
    dy1message(F("con"));
    drawMsgBox(F("Wi-Fi"), F("Connect"), DB_INFO);
    serverInit();
    #ifdef USE_DY1_DISPLAY
      // display IP address on the 3-digit 7-segment display for a few seconds.
      if (currentWifiMode == WifiMode_STA) {
        for (int i = 0; i < 4; ++i) {
          dy1number(WiFi.localIP()[i], i == 3 ? -1 : 2); // Display the last octet of the IP address
          delay(350);
        }
      } else {
        for (int i = 0; i < 4; ++i) {
          dy1number(WiFi.softAPIP()[i], i == 3 ? -1 : 2); // Display the last octet of the IP address
          delay(350);
        }
      }
      Serial.println(F("Server started."));
      delay(500); // additional delay to make the last digit visible for a bit longer
      dy1message(wifiModeLabel);
      delay(500); 
      dy1message(F("on "));
      delay(500);
    #endif
    if (currentWifiMode == WifiMode_STA) {
      drawStringBox(F("STA Mode"), WiFi.localIP().toString());
    } else {
      drawStringBox(F("AP Mode"), WiFi.softAPIP().toString());
    }
    printWebInfo();
  #else
    dy1message(F("off"));
    drawMsgBox(F("Wi-Fi"), F("OFF"), DB_INFO);
  #endif
   
  listLittleFsEntries();
  printFileInfo();
  // printSerialCommandsInfo();
  delay(1000);
  readyMessage();
  Serial.println(F("\nReady."));
}

  
// Main service loop for serial commands, HTTP handling, and playback.
void loop() {
  processSerialCommands();
  #ifdef USE_WEB_SERVER
    server.handleClient();
  #endif
  if (millis() > msgTimeout) {
    setUpSendLed(false);
    drawStatusBox();
    msgTimeout = -1; // reset timeout to avoid repeated drawing
  }
}

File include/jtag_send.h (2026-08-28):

#ifndef JTAG_SEND_H
#define JTAG_SEND_H

// ##############################################################################
//
//           # #######    #     #####      #####  ####### #     # ######  
//           #    #      # #   #     #    #     # #       ##    # #     # 
//           #    #     #   #  #          #       #       # #   # #     # 
//           #    #    #     # #  ####     #####  #####   #  #  # #     # 
//     #     #    #    ####### #     #          # #       #   # # #     # 
//     #     #    #    #     # #     #    #     # #       #    ## #     # 
//      #####     #    #     #  #####      #####  ####### #     # ######  
//                                                                        
// ##############################################################################
// SEND JTAG CONFIGURATION FROM LITTLEFS
// ##############################################################################

// Optimized for speed on ESP8266 using direct GPIO register access and faster loops 
// by Carsten Meyer 7/2026, info@keyboardpartner.de
// Brought down configuration time for a 334 KByte bitstream from 3.4 seconds to 921 ms (!) on ESP8266

// Note: It might be possible to speed up even more using the SPI for shifting out the data
// stream bytes. However, behaviour of the SPI pins on ESP8266 on begin()/end() is not determined
// and might be unstable, so we stick to bit-banging for now.

// Note that the pins used here for bit banging are easy accessible on the ESP8266.
// GPIO16 (User/D0) does not map to the standard GPOS/GPOC registers and cannot use this method.

// Based on a sketch by RSP @ Embedded Systems Lab (ESL), KMUTNB, Bangkok / Thailand
// Date: 2017-07-06
// Objective: This sketch shows how to use an ESP8266 module to
//   configure the Xilinx Spartan-6 FPGA device using the JTAG port.
//   The bitstream file ("TOP.BIN") and its associated MD5 checksum file ("TOP.MD5")
//   are stored in a microSD attached to the ESP8266 via the SPI bus.
//   The MD5 checksum calculation is performed first before loading the bitstream.
//   This sketch can successfully load the bitstream into the Xilinx Spartan 6SLX9
//   FPGA device on the Mojo v3 board.

#include <Arduino.h>
#include <LittleFS.h>
#include <cstdlib>
#include <cstdio>
#include "global_vars.h" // for some #defines

// ESP8266 Pins for JTAG: 
const int TCK_PIN = 5; // D1 / GPIO-5 (output)
const int TDO_PIN = 4; // D2 / GPIO-4 (input)
const int TDI_PIN = 0; // D3 / GPIO-0 (output)
const int TMS_PIN = 2; // D4 / GPIO-2 (output)

#define MAX_BUF_SIZE (4096)

// union of 8 and 32 bit buffer for faster access -- does not pay due to wrong byte order
// union {
//   uint8_t bytes[MAX_BUF_SIZE];
//   uint32_t words[MAX_BUF_SIZE / 4];
// } buffer;

uint8_t buf[MAX_BUF_SIZE];

uint32_t jtagIDcode = 0;
uint32_t fpgaVersion = 0;
bool fpgaValid = false;
bool fpgaConfigured = false;

// see: Spartan-6 FPGA Configuration User Guide UG380 (v2.10) March 31, 2017
#define XILINX_IR_LEN             (6)
#define XILINX_USER1_INSTR        (0x02)  // 000010
#define XILINX_USER2_INSTR        (0x03)  // 000011
#define XILINX_USER3_INSTR        (0x1A)  // 011010
#define XILINX_USER4_INSTR        (0x1B)  // 011011
#define XILINX_CFG_OUT_INSTR      (0x04)  // 000100
#define XILINX_CFG_IN_INSTR       (0x05)  // 000101
#define XILINX_BYPASS_INSTR       (0x3F)  // 111111
#define XILINX_IDCODE_INSTR       (0x09)  // 001001
#define XILINX_USERCODE_INSTR     (0x08)  // 001000
#define XILINX_JPROGRAM_INSTR     (0x0B)  // 001011
#define XILINX_JSTART_INSTR       (0x0C)  // 001100
#define XILINX_JSHUTDOWN_INSTR    (0x0D)  // 001101 
#define XILINX_S6LX9_IDCODE       (0x04001093)  // Spartan-6 LX9 FPGA device ID code
#define XILINX_3S400_IDCODE       (0x0141C093)  // Spartan-3 S400 FPGA device ID code


// ##############################################################################
//
//     #     # ####### #       ######  ####### ######   #####  
//     #     # #       #       #     # #       #     # #     # 
//     #     # #       #       #     # #       #     # #       
//     ####### #####   #       ######  #####   ######   #####  
//     #     # #       #       #       #       #   #         # 
//     #     # #       #       #       #       #    #  #     # 
//     #     # ####### ####### #       ####### #     #  #####  
//                                                             
// ##############################################################################
// Optimized for speed on ESP8266 using direct GPIO register access
// ##############################################################################

// inline codes for bit banging the JTAG signals on ESP8266
#define TMS_HIGH  GPOS = (1<<TMS_PIN)
#define TMS_LOW   GPOC = (1<<TMS_PIN)
#define TCK_HIGH  GPOS = (1<<TCK_PIN)
#define TCK_LOW   GPOC = (1<<TCK_PIN)
#define TDI_HIGH  GPOS = (1<<TDI_PIN)
#define TDI_LOW   GPOC = (1<<TDI_PIN)

#define TCK_PULSE  GPOC = (1<<TCK_PIN); GPOS = (1<<TCK_PIN)

void jtag_tl_reset() {
  TMS_HIGH;
  for ( int i=0; i < 5; i++ ) {
    TCK_PULSE;
  }
}

void jtag_goto_runtest_idle() {
  jtag_tl_reset();
  TMS_LOW;
  TCK_PULSE;  // goto Run-Test/Idle
}

void jtag_load_ir(uint32_t instr) {
  // start from Run-Test/Idle state
  jtag_goto_runtest_idle();
  TMS_HIGH;
  TCK_PULSE;  // goto Select-DR-Scan
  TCK_PULSE;  // goto Select-IR-Scan
  TMS_LOW;
  TCK_PULSE;  // goto Capture-IR
  TCK_PULSE;  // goto shift-IR
  for ( int i=0; i < XILINX_IR_LEN; i++ ) {
    // shift LSB first
    if (instr & 1) {
       TDI_HIGH;
     } else {
       TDI_LOW;
     }
     // leave with TMS high on last bit to go to Exit1-IR state
     if (i==(XILINX_IR_LEN-1)) {
       TMS_HIGH;
     }
     TCK_PULSE; // goto Exit1-IR or shift-DR
     instr = (instr >> 1);
  }
  // TMS is still high, so we are now in Exit1-IR state
  TCK_PULSE;  // goto Update-IR
  TMS_LOW;
  TCK_PULSE;  // back Run-Test/Idle
}

void jtag_shift_last_byte(uint8_t data) {
  // shift the last byte with TMS high on last bit
  for ( int i=0; i < 8; i++ ) {           // for each bit of the byte data
    if (i==7) {  // check for the last bit
      TMS_HIGH;  // goto Exit1-DR on last bit
    }     
    if (data & 0x80) {
      TDI_HIGH;
    } else {
      TDI_LOW;
    }
    data = data << 1;                     // shift-to-left
    TCK_PULSE;
  }
}
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

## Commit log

2026-07-27 added pcb
    [esim_esp_reversed.sch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]
2026-07-27 added pin info
2026-08-04 new web interface
    [50Mhz_teiler1.xlsx, dil28_27256_62256.sch, dil28_tester.sch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]
2026-08-05 added support for PEPS EPROM simulator
    [esim_esp_reversed.sch, peps_esp.sch, via_loader.sch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]
2026-08-05 added PCBs
    [esim_esp_reversed.sch, godil_esp.sch, peps_esp.sch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]
2026-08-06 moved files
    [dil28_27256_62256.sch, dil28_tester.sch, esim_esp_reversed.sch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]
2026-08-10 added support for MOJO FPGA
    [esim_esp_reversed.sch, jtag_esp.sch, jtag_esp_reversed.sch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]
2026-08-11 heavy refactoring to reduce main.cpp size
    [MOJO_FPGA_pinout.xlsx, jtag_esp.sch, jtag_esp_reversed.sch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]
2026-08-12 added fpga sources
    [fpga_main.sch]
2026-08-12 minor changes
    [jtag_esp.sch]
2026-08-12 added UCF for GODIL
    [via_loader.sch]
2026-08-13 removed unused files
    [rom_adapter.sch, rom_adapter_2.sch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]
2026-08-14 moved files for convenience
    [MOJO_FPGA_pinout.xlsx, dil28_27256_62256.sch, dil28_tester.sch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]
2026-08-18 added support for small status TFT
    [MOJO_FPGA_pinout.xlsx, fpga_main.sch, jtag_esp_dil_cable.sch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]
2026-08-19 new MOJO board 2-layer
    [BOM_jtag_esp_dil_cable_tft (Excel for JLPCB).csv, fpga_main.sch, jtag_esp_dil_cable_tft (Excel for JLPCB).csv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]
2026-08-21 Added support for Picoblaze cores
    [jtag_esp_simple.sch, jtag_esp_tft.sch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]
2026-08-21 added files for Picoblaze support
    [mojo_pb_test.sch, picoblaze_test.psm]
2026-08-23 optimized fast_spi32
    [fpga_main.sch, mojo_pb_test.sch]
2026-08-23 added Picoblaze example for GODIL
    [picoblaze_test.psm]
2026-08-26 support for new FPGA config
    [MOJO_FPGA_pinout.xlsx, jtag_esp_dil_cable_tft.sch, jtag_esp_tft.sch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]
2026-08-28 bugfix for jtag send
    [global_vars.h, jtag_send.h, main.cpp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]

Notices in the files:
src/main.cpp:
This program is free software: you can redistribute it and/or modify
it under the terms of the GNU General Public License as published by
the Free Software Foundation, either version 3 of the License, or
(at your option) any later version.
